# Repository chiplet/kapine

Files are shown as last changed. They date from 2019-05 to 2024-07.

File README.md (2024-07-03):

# KAPINE
Kircular Accelerator Prototype Innovative New Experience

# Setup

## KiCAD Library Setup
Run the following command to install the third party KiCAD libraries used in the project

`git submodule update --init --recursive`

This project uses components from [digikey-kicad-library](https://github.com/Digi-Key/digikey-kicad-library) which is configured as a git submodule of this project. Git doesn't clone submodules of a project by default when the project it is cloned so this has to be done manually.

# Hardware

## Pinout

**Application Signal Descriptions**
* m[0..15] -- Electromagnet control signals
* s[0..15] -- Photogate sensor input signals
* Debug 1 -- Debug led 1
* Debug 2 -- Debug led 2
* USART1 -- Command link UART

| Microcontroller Pin | Application Signal | Direction | Alternate Function |
|---|---|---|---|
| PB5 | m0 | Digital out | TBD |
| PD2 | m1 | Digital out | TBD |
| PC11 | m2 | Digital out | TBD |
| PA12 | m3 | Digital out | TBD |
| PA8 | m4 | Digital out | TBD |
| PC8 | m5 | Digital out | TBD |
| PC6 | m6 | Digital out | TBD |
| PB14 | m7 | Digital out | TBD |
| PB11 | m8 | Digital out | TBD |
| PB2 | m9 | Digital out | TBD |
| PC5 | m10 | Digital out | TBD |
| ~~PA3~~ PA4 | m11 | Digital out | TBD |
| PC3 | m12 | Digital out | TBD |
| PC1 | m13 | Digital out | TBD |
| PB9 | m14 | Digital out | TBD |
| PB7 | m15 | Digital out | TBD |
| PB4 | s0 | Digital in  | TBD |
| ~~PC12~~ PA3 | s1 | Digital in  | TBD |
| PC10 | s2 | Digital in  | TBD |
| PA11 | s3 | Digital in  | TBD |
| PC9 | s4 | Digital in  | TBD |
| PC7 | s5 | Digital in  | TBD |
| PB15 | s6 | Digital in  | TBD |
| PB13 | s7 | Digital in  | TBD |
| PB10 | s8 | Digital in  | TBD |
| PB1 | s9 | Digital in  | TBD |
| ~~PC4~~ PC14 | s10 | Digital in  | TBD |
| PA2 | s11 | Digital in  | TBD |
| ~~PC2~~ PA5 | s12 | Digital in  | TBD |
| PC0 | s13 | Digital in  | TBD |
| PB8 | s14 | Digital in  | TBD |
| PB6 | s15 | Digital in  | TBD |
| PA0 | Debug 1 | Digital out | TBD |
| PA1 | Debug 2 | Digital out | TBD |
| PA9 | USART1_TX | Digital out | AF7 |
| PA10 | USART1_RX | Digital in  | AF7 |
| PC13 | RGB LEDs | Digital out | TBD |

### Change Log
* 2021-08-07: STM32F3 maps GPIO to EXTI interrupts based on pin number. The following changes needed to be made to support interrupts on all sensor input pins:
  * m11 (PA3 -> PA4)
  * s2 (PC10 -> PA3)
  * s12 (PC2 -> PA5)
  * s10 (PC4 -> PC14)

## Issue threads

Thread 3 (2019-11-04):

Acrylic core with a detachable section for module interchange

chiplet, 2019-11-04:
* [x] Find where to buy appropriate acrylic tubing
* [ ] How to bend the tube to a perfect circle?
* [ ] Make jig for bending the tube

chiplet, 2024-07-03:
Acrylic was difficult to bend consistently so going for bare 3D printed accelerator tube.

Closed 2024-07-03.

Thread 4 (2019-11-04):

Self-contained accelerator modules with integrated sensors, communication bus, actuators, and debug interface

VerkkuUkkeli, 2019-11-04:
TODO: elaborate

VerkkuUkkeli, 2019-12-21:
Duplicate of #6

VerkkuUkkeli, 2019-12-21:
Reconsidering this, #6 is more about the electronics design for the segment control unit. This issue is about the status of the whole segment, including electrical and mechanical design.

VerkkuUkkeli, 2020-01-26:
SCUs will be no longer used so the issue is obsolete.

Closed 2020-01-26.

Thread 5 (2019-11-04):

Design motherboard v1

chiplet, 2019-11-04:
General:
* [x] choose microcontroller [STM32F303RE](https://www.digikey.fi/products/fi/integrated-circuits-ics/embedded-microcontrollers/685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)
* [x] board schematics
* [x] board layout

Power Supply:
* It's probably best to use a separate power supply for powering the electromagnet coils and the control circuitry to avoid EMC issues
* [x] regulate required voltages from an external wall wart
  * [x] 3.3V for the microcontroller digital logic
  * [x] 3.3V microcontroller analog reference

Interfaces:
* [x] JTAG
* [x] ST-LINK/V2-1 debugger
* [x] stack connector(s) to electromagnet driver board

TODO:
* [x] Logic level conversion from mcu to RGB

Ottis1, 2019-12-21:
This is not needed anymore since motherboard functionality is assigned to one of the segments?

VerkkuUkkeli, 2020-01-26:
MCU selection:
* All analog circuitry (photo gate sensors) shall convert their measures to digital format so the microcontroller does not have to deal with analog signals.

MCU requirements
* [ ] Enough GPIO pins (at least to support for adding IO expansion for all required signals)
  * segment indicator LEDs (16)
  * motherboard RGB (1)
  * driver board RGB (1) (can be chained with motherboard RGB)
  * electromagnet control signals (16)
  * debug UART (2)
* [ ] UART
* [ ] QFP package

VerkkuUkkeli, 2020-01-26:
## GPIO expansion considerations
Segment indicator LEDs can be driven with the control signals without much issue. A good solution would be to use a LED driver IC with 16 outputs and serial control interface, or maybe even a shift register.

IO expansion ICs allow for bidirectional I/O. This is not necessary for the segment indicators, but would be useful for reading sensors.

Shift registers:
[SN74HC595](https://www.digikey.fi/product-detail/fi/texas-instruments/SN74HC595PWR/296-23258-1-ND/1830780) is currently used for prototyping. These can be chained so 16 indicator LEDs can be controlled over a serial connection with 3 lines in total.

VerkkuUkkeli, 2020-08-16:
## MCU Implementation

TODO:
[ ] Copy reference design from STM32F3 hardware development [app note](https://www.st.com/resource/en/application_note/dm00070391-getting-started-with-stm32f3-series-hardware-development-stmicroelectronics.pdf)

chiplet, 2020-10-31:
First revision design is complete!

Closed 2020-10-31.

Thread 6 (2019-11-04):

Design Segment Control Unit (SCU) v1 electronics

VerkkuUkkeli, 2019-11-04:
General:
* [x] choose microcontroller
* [ ] sensor circuit
* [ ] electromagnet driver circuit
* [ ] board schematics
* [ ] board layout

Interfaces:
* [x] design debugger interface -- using SWD from STM32F0DISCOVERY board (ST-LINK/V2)
* [x] choose communication bus

VerkkuUkkeli, 2019-11-04:
MCU functions:
* photogate sensor(s)
  - read sensor value (analogue)
  - control IR diode
* drive high(ish) voltage electromagnet
  - control relay/FET
* indicator led(s) for magnet position
* debug
  - UART

MCU requirements
* [ ] ADC
* [ ] GPIO (at least 3)
* [ ] UART
* [ ] Small footprint
* [ ] QFP package
* [ ] Low cost

VerkkuUkkeli, 2019-12-18:
[STM32F072C8T6TR](https://www.digikey.fi/product-detail/en/stmicroelectronics/STM32F072C8T6TR/497-17359-1-ND/8024128) looks like a suitable MCU.

[datasheet](https://www.st.com/content/ccc/resource/technical/document/datasheet/cd/46/43/83/22/d3/40/c8/DM00090510.pdf/files/DM00090510.pdf/jcr:content/translations/en.DM000905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)

VerkkuUkkeli, 2019-12-18:
Also remember to by a [STM32F0 discovery](https://www.digikey.fi/product-detail/en/stmicroelectronics/STM32F0DISCOVERY/497-12876-ND/3045359) board for flashing.

VerkkuUkkeli, 2019-12-18:
TODO:
* [ ] Choose regulator(s) for MCU
* [ ] Choose flashing interface connector
* [ ] Choose FETs / relays used
* [ ] Choose CAN transceiver

VerkkuUkkeli, 2019-12-21:
HSE crystal selection:

[ECS-80-18-30B-JEM-TR](https://www.digikey.fi/product-detail/fi/ecs-inc/ECS-80-18-30B-JEM-TR/XC2105CT-ND/5875589) seems suitable.

gain margin = 18.7 (> 5 so all good)

computed with values:
* ESR = 100 ohm
* C_L = 18pF
* C_0 = 5pF
* F = 8 MHz
* g_m = 10 mA/V

See [AN2867](https://www.st.com/content/ccc/resource/technical/document/application_note/c6/eb/5e/11/e3/69/43/eb/CD00221665.pdf/files/CD00221665.pdf/jcr:content/translations/en.C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) section 3.4 for formulae

VerkkuUkkeli, 2019-12-22:
There probably isn't going to be enough space for a relay... :(

Relays would be nice because they make nice clicking sounds, but they are slow and big compared to load switches. Load switches also seem to be preferable over using plain FETs as they have adequate current and voltage range (4A at 12V) with much smaller footprint and additional protection circuitry.

[BTS50451EJAXUMA1](https://www.digikey.fi/product-detail/fi/infineon-technologies/BTS50451EJAXUMA1/BTS50451EJAXUMA1CT-ND/5413734) seems promising for the electromagnet driver. The max load inductance must still be verified to see if this IC can be used for driving the electromagnet.

VerkkuUkkeli, 2020-01-26:
SCUs will be no longer used so the issue is obsolete.

Closed 2020-01-26.

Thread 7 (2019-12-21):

Configure SCU CAN peripheral

VerkkuUkkeli, 2019-12-21:
Configure STM32F072 bxCAN peripheral for use.

TODO:
* [ ] Enable peripheral clock (CANEN bit in RCC_APB1ENR register)
* [ ] Configure APB clock (PCLK)
* [ ] Bit timing -- prescaler for bxCAN
* [ ] Bit timing -- nominal bit timing and sample point ([see spec](http://esd.cs.ucr.edu/webres/can20.pdf))

VerkkuUkkeli, 2019-12-21:
The bxCAN peripheral uses APB bus clock (PCLK).

VerkkuUkkeli, 2020-01-26:
SCUs will be no longer used so the issue is obsolete.

Closed 2020-01-26.

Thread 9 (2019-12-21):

Segment CAD design

chiplet, 2019-12-21:
CAD design for accelerator segments

TODO and things to consider:
* [x] accommodate segment PCBs
* [x] accommodate photo gate sensor
* [x] accommodate electromagnet
* [ ] ~~places for electrical connectors for inter-module connections (chain units together)~~
* [ ] cable management
* [ ] EMC issues and wiring placement (try to minimise interference by smart cable routing)
* [x] how to manufacture, design with manufacturing in mind (3D printing?)

TODO: add more considerations as they come up

VerkkuUkkeli, 2020-02-20:
## Sensor placement considerations:
* [ ] Should the pipe have a hole for mounting the sensors
  * [ ] Test if the sensor works through the pipe without mounting holes

VerkkuUkkeli, 2020-03-21:
Relays / FETs are placed on top of the motherboard so there will be no need to try to accommodate them in the segments.

Ottis1, 2021-01-19:
It seems to me that only the cable management and wiring placement considerations are left in this issue. Controlling the segments happens on the motherboard so there will be no segment PCBs. Also, in my understanding the units will not be chained together in any way.
3D printing was chosen as the manufacturing method.

chiplet, 2024-07-06:
Segments have been designed and printed already

Closed 2024-07-06.

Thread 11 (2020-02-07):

Motherboard clock configuration

chiplet, 2020-02-07:
Configure the MCU to use the HSE as the clock source.

The following part of the [hardware design guide](https://www.st.com/content/ccc/resource/technical/document/application_note/31/14/f4/9d/d3/8f/48/2b/DM00070391.pdf/files/DM00070391.pdf/jcr:content/translations/en.D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) seems useful for software configuration:
"The HSERDY flag in the Clock control register (RCC_CR) indicates if the HSE oscillator is
stable or not. At startup, the clock is not released until this bit is set by hardware. An
interrupt can be generated if enabled in the Clock interrupt register (RCC_CIR).
The HSE Crystal can be switched on and off using the HSEON bit in the Clock control
register (RCC_CR)."

chiplet, 2024-07-06:
Done. The stm32f3xx-hal crate offers a convenient interface for configuring core and peripheral clocks:
https://docs.rs/stm32f3xx-hal/0.10.0/stm32f3xx_hal/rcc/index.html

Closed 2024-07-06.

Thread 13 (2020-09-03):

Design relelauta v.2.0

chiplet, 2020-09-03:
# Abbreviations
* EM - electromagnet

# TODO:
* [x] Measure EM inductance
* [x] Choose EM driver
  * Relay?
  * Load switch?
  * MOSFET?
* [ ] Indicator LEDs for EM drivers
  * [ ] Amplifiers for indicator led signal so that EM control signals are not loaded by the LEDs

## Electromagnet Specifications
* Resistance ~2 Ohm
* Inductance ~ 430 µH
=> Assuming 10A current, energy stored in inductor is E = 22mJ

## Electromagnet driver selection considerations
* High enough load current (around 10A, TBD)
* High enough power package to withstand generated heat
* Be able to withstand inductive "kicks" when switching off the electromagnet
  * Are external flywheel diodes required?
* Nice enough package for easy soldering

chiplet, 2021-01-18:
STM32 GPIO pins are a bit problematic, at least on the Blue Pill dev board. According to the reference manual, the GPIO pins should reset to floating input configuration. The configuration register contents match this configuration when inspecting memory. However, for whatever reason, when measured, the pin is pulled up to 3.3V. The boards were ordered from ebay so the issue might be that the MCU on the devboard is actually a clone which doesn't implement the floating state correctly.

Whatever the reason, this is problematic since when the pin is pulled to 3.3V an electromagnet controlled by the pin would turn on. This is not an issue after the pin has been configured as an output. However, when debugging with a breakpoint set to main, this would turn on **all** electromagnets by default at the same time and the electronics are not designed to handle that.

As a workaround I'm connecting an external 1k pull-down resistor which seems to pull the pin to around 0.7V when left "floating".

Closed 2021-05-16.

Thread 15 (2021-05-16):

Motherboard firmware

Ottis1, 2021-05-16:
Develop the firmware for the motherboard which controls the electromagnets, reads the sensors and communicates with the PC command interface via a serial connection.

TODO:

- [ ] serial communication
- [ ]

chiplet, 2024-07-06:
**TODO:**
- [ ] Serial communication
  - [ ] USART1 driver
  - [ ] Packet-based request-acknowledge command link
- [x] RGB animation (make it look like cool alien brains!)
- [ ] Sensor input interrupts
- [ ] Acceleration control sequencing

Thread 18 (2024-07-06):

Motherboard v1.3

chiplet, 2024-07-06:
Create a new motherboard hardware revision fixing the pin assignment issues in motherboard v1.2. At least RGB data signal has been moved to PA7 corresponding to SPI1_MOSI with AF5.

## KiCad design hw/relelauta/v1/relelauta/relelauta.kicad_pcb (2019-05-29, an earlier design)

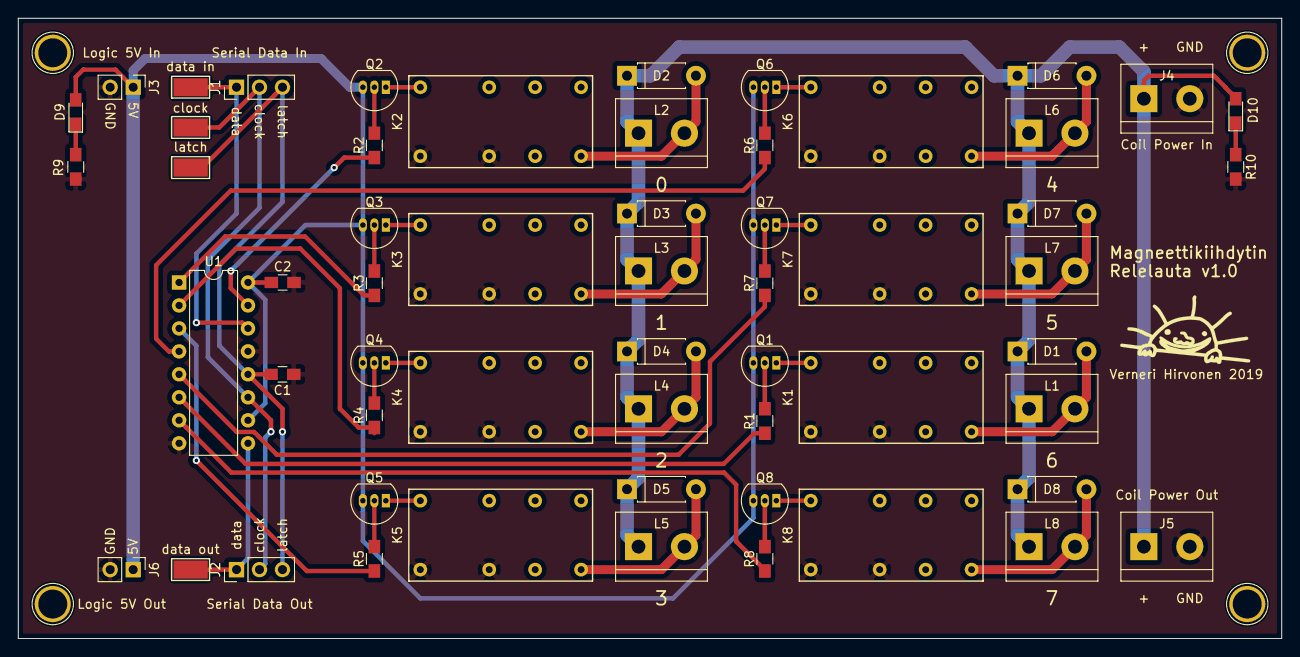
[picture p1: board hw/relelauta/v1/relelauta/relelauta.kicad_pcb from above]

Board: 2 copper layers, 139.7 x 68.6 mm, 57 parts (0 on the bottom side), 41 nets.

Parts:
C1, C2: 100n; C_0805_HandSoldering
D1, D2, D3, D4, D5, D6, D7, D8: 1N4001; D_DO-41_SOD81_P7.62mm_Horizontal
D9: ARDUINO; LED_0805_HandSoldering
D10: COIL; LED_0805_HandSoldering
J1: serial_in; Pin_Header_Straight_1x03_Pitch2.54mm
J2: serial_out; Pin_Header_Straight_1x03_Pitch2.54mm
J3: arduino_5V; Pin_Header_Straight_1x02_Pitch2.54mm
J4: coil_power_in; TerminalBlock_bornier-2_P5.08mm
J5: coil_power_out; TerminalBlock_bornier-2_P5.08mm
J6: 5V_out; Pin_Header_Straight_1x02_Pitch2.54mm
K1: relay 7; RY5W-K
K2: relay 1; RY5W-K
K3: relay 2; RY5W-K
K4: relay 3; RY5W-K
K5: relay 4; RY5W-K
K6: relay 5; RY5W-K
K7: relay 6; RY5W-K
K8: relay 8; RY5W-K
L1: coil7; TerminalBlock_bornier-2_P5.08mm
L2: coil1; TerminalBlock_bornier-2_P5.08mm
L3: coil2; TerminalBlock_bornier-2_P5.08mm
L4: coil3; TerminalBlock_bornier-2_P5.08mm
L5: coil4; TerminalBlock_bornier-2_P5.08mm
L6: coil5; TerminalBlock_bornier-2_P5.08mm
L7: coil6; TerminalBlock_bornier-2_P5.08mm
L8: coil8; TerminalBlock_bornier-2_P5.08mm
Q1, Q2, Q3, Q4, Q5, Q6, Q7, Q8: 2N3904; TO-92_Inline_Narrow_Oval
R1, R2, R3, R4, R5, R6, R7, R8: 1k; R_0805_HandSoldering
R9, R10: 10k; R_0805_HandSoldering
U1: 74HC595; DIP-16_W7.62mm
clock: clock; Test_Point_Keystone_5019_Minature
data in: data_in; Test_Point_Keystone_5019_Minature
data out: data_out; Test_Point_Keystone_5019_Minature
latch: latch; Test_Point_Keystone_5019_Minature

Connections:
+5V: C2.1, D9.2, J3.1, J6.1, Q1.3, Q2.3, Q3.3, Q4.3, Q5.3, Q6.3, Q7.3, Q8.3, U1.10, U1.16
GND: C1.1, C2.2, J3.2, J4.2, J5.2, J6.2, K1.21, K1.A2, K2.21, K2.A2, K3.21, K3.A2, K4.21, K4.A2, K5.21, K5.A2, K6.21, K6.A2, K7.21, K7.A2, K8.21, K8.A2, R9.2, R10.2, U1.8, U1.13
unnamed: D1.2, K1.24, L1.2
unnamed: D2.2, K2.24, L2.2
unnamed: D3.2, K3.24, L3.2
unnamed: D4.2, K4.24, L4.2
unnamed: D5.2, K5.24, L5.2
unnamed: D6.2, K6.24, L6.2
unnamed: D7.2, K7.24, L7.2
unnamed: D8.2, K8.24, L8.2
unnamed: D9.1, R9.1
unnamed: D10.1, R10.1
unnamed: K1.A1, Q1.1
unnamed: K2.A1, Q2.1
unnamed: K3.A1, Q3.1
unnamed: K4.A1, Q4.1
unnamed: K5.A1, Q5.1
unnamed: K6.A1, Q6.1
unnamed: K7.A1, Q7.1
unnamed: K8.A1, Q8.1
unnamed: Q1.2, R1.2
unnamed: Q2.2, R2.2
unnamed: Q3.2, R3.2
unnamed: Q4.2, R4.2
unnamed: Q5.2, R5.2
unnamed: Q6.2, R6.2
unnamed: Q7.2, R7.2
unnamed: Q8.2, R8.2
V_coil: D1.1, D2.1, D3.1, D4.1, D5.1, D6.1, D7.1, D8.1, D10.2, J4.1, J5.1, L1.1, L2.1, L3.1, L4.1, L5.1, L6.1, L7.1, L8.1
clock: J1.2, J2.2, U1.11, clock.1
data_in: J1.1, U1.14, data in.1
data_out: J2.1, U1.9, data out.1
latch: C1.2, J1.3, J2.3, U1.12, latch.1
signal1: R2.1, U1.15
signal2: R3.1, U1.1
signal3: R4.1, U1.2
signal4: R5.1, U1.3
signal5: R6.1, U1.4
signal6: R7.1, U1.5
signal7: R1.1, U1.6
signal8: R8.1, U1.7

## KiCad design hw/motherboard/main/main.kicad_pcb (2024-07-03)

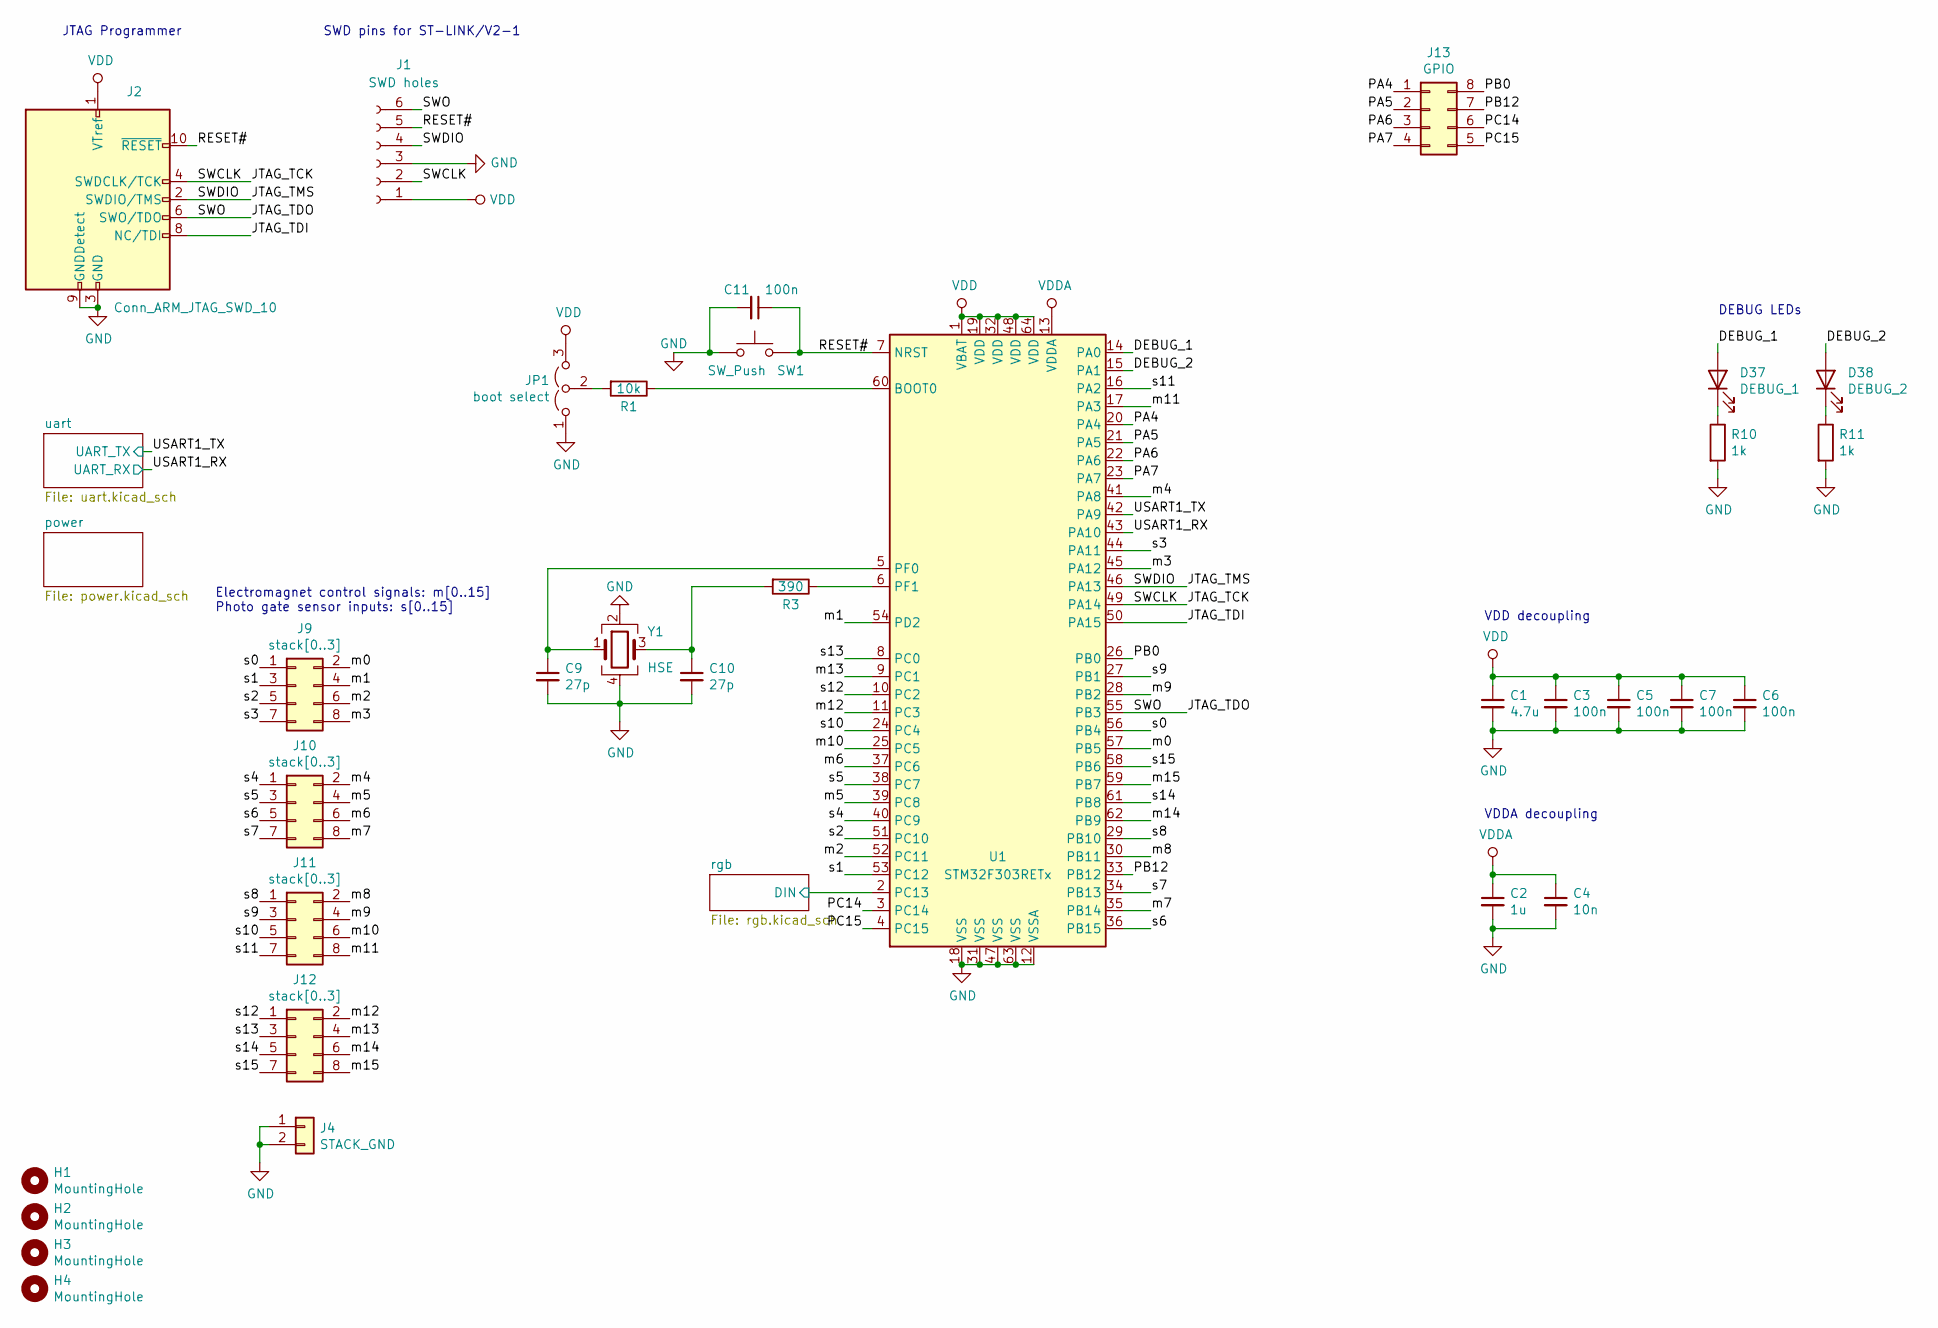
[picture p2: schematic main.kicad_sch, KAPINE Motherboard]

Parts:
C1: 4.7u; C_0805_2012Metric
C2: 1u; C_0603_1608Metric
C3, C5, C6, C7, C11: 100n; C_0603_1608Metric
C4: 10n; C_0603_1608Metric
C9, C10: 27p; C_0603_1608Metric
D37: DEBUG_1; LED_0805_2012Metric
D38: DEBUG_2; LED_0805_2012Metric
H1, H2, H3, H4: MountingHole; MountingHole_4.3mm_M4
J1: SWD holes; PinHeader_1x06_P2.54mm_Vertical
J2: Conn_ARM_JTAG_SWD_10; PinHeader_2x5_P1.27mm_Drill.7mm
J4: STACK_GND; PinSocket_1x02_P2.54mm_Vertical
J9, J10, J11, J12: stack[0..3]; PinSocket_2x04_P2.54mm_Vertical
J13: GPIO; PinHeader_2x04_P2.54mm_Vertical
JP1: boot select; PinHeader_1x03_P2.54mm_Vertical
R1: 10k; R_0603_1608Metric
R3: 390; R_0603_1608Metric
R10, R11: 1k; R_0805_2012Metric
SW1: SW_Push; SW_SPST_TL3342
U1: STM32F303RETx; LQFP-64_10x10mm_P0.5mm
Y1: HSE; Crystal_SMD_Abracon_ABM3C-4Pin_5.0x3.2mm

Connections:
/DEBUG_1: D37.2 (A), U1.14 (PA0)
/DEBUG_2: D38.2 (A), U1.15 (PA1)
/JTAG_TCK: J1.2, J2.4 (SWDCLK/TCK), U1.49 (PA14)
/JTAG_TDI: J2.8 (NC/TDI), U1.50 (PA15)
/JTAG_TDO: J1.6, J2.6 (SWO/TDO), U1.55 (PB3)
/JTAG_TMS: J1.4, J2.2 (SWDIO/TMS), U1.46 (PA13)
/PA4: J13.1, U1.20 (PA4)
/PA5: J13.2, U1.21 (PA5)
/PA6: J13.3, U1.22 (PA6)
/PA7: J13.4, U1.23 (PA7)
/PB0: J13.8, U1.26 (PB0)
/PB12: J13.7, U1.33 (PB12)
/PC14: J13.6, U1.3 (PC14)
/PC15: J13.5, U1.4 (PC15)
/RESET#: C11.1, J1.5, J2.10 (~RESET), SW1.2, U1.7 (NRST)
/USART1_RX: U1.43 (PA10); also elsewhere on the board
/USART1_TX: U1.42 (PA9); also elsewhere on the board
/m0: J9.2, U1.57 (PB5)
/m1: J9.4, U1.54 (PD2)
/m2: J9.6, U1.52 (PC11)
/m3: J9.8, U1.45 (PA12)
/m4: J10.2, U1.41 (PA8)
/m5: J10.4, U1.39 (PC8)
/m6: J10.6, U1.37 (PC6)
/m7: J10.8, U1.35 (PB14)
/m8: J11.2, U1.30 (PB11)
/m9: J11.4, U1.28 (PB2)
/m10: J11.6, U1.25 (PC5)
/m11: J11.8, U1.17 (PA3)
/m12: J12.2, U1.11 (PC3)
/m13: J12.4, U1.9 (PC1)
/m14: J12.6, U1.62 (PB9)
/m15: J12.8, U1.59 (PB7)
/rgb/DIN: U1.2 (PC13); also elsewhere on the board
/s0: J9.1, U1.56 (PB4)
/s1: J9.3, U1.53 (PC12)
/s2: J9.5, U1.51 (PC10)
/s3: J9.7, U1.44 (PA11)
/s4: J10.1, U1.40 (PC9)
/s5: J10.3, U1.38 (PC7)
/s6: J10.5, U1.36 (PB15)
/s7: J10.7, U1.34 (PB13)
/s8: J11.1, U1.29 (PB10)
/s9: J11.3, U1.27 (PB1)
/s10: J11.5, U1.24 (PC4)
/s11: J11.7, U1.16 (PA2)
/s12: J12.1, U1.10 (PC2)
/s13: J12.3, U1.8 (PC0)
/s14: J12.5, U1.61 (PB8)
/s15: J12.7, U1.58 (PB6)
GND: C1.2, C2.2, C3.2, C4.2, C5.2, C6.2, C7.2, C9.2, C10.2, C11.2, J1.3, J2.3 (GND), J2.5 (GND), J2.9 (GNDDetect), J4.1, J4.2, JP1.1 (A), R10.2, R11.2, SW1.1, U1.12 (VSSA), U1.18 (VSS), U1.31 (VSS), U1.47 (VSS), U1.63 (VSS), Y1.2, Y1.4; also elsewhere on the board
unnamed: C9.1, U1.5 (PF0), Y1.1
unnamed: C10.1, R3.2, Y1.3
unnamed: D37.1 (K), R10.1
unnamed: D38.1 (K), R11.1
unnamed: JP1.2 (C), R1.2
unnamed: R1.1, U1.60 (BOOT0)
unnamed: R3.1, U1.6 (PF1)
VDD: C1.1, C3.1, C5.1, C6.1, C7.1, J1.1, J2.1 (VTref), JP1.3 (B), U1.1 (VBAT), U1.19 (VDD), U1.32 (VDD), U1.48 (VDD), U1.64 (VDD); also elsewhere on the board
VDDA: C2.1, C4.1, U1.13 (VDDA); also elsewhere on the board

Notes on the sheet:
VDD decoupling
Electromagnet control signals: m[0..15] Photo gate sensor inputs: s[0..15]
SWD pins for ST-LINK/V2-1
JTAG Programmer
DEBUG LEDs
VDDA decoupling

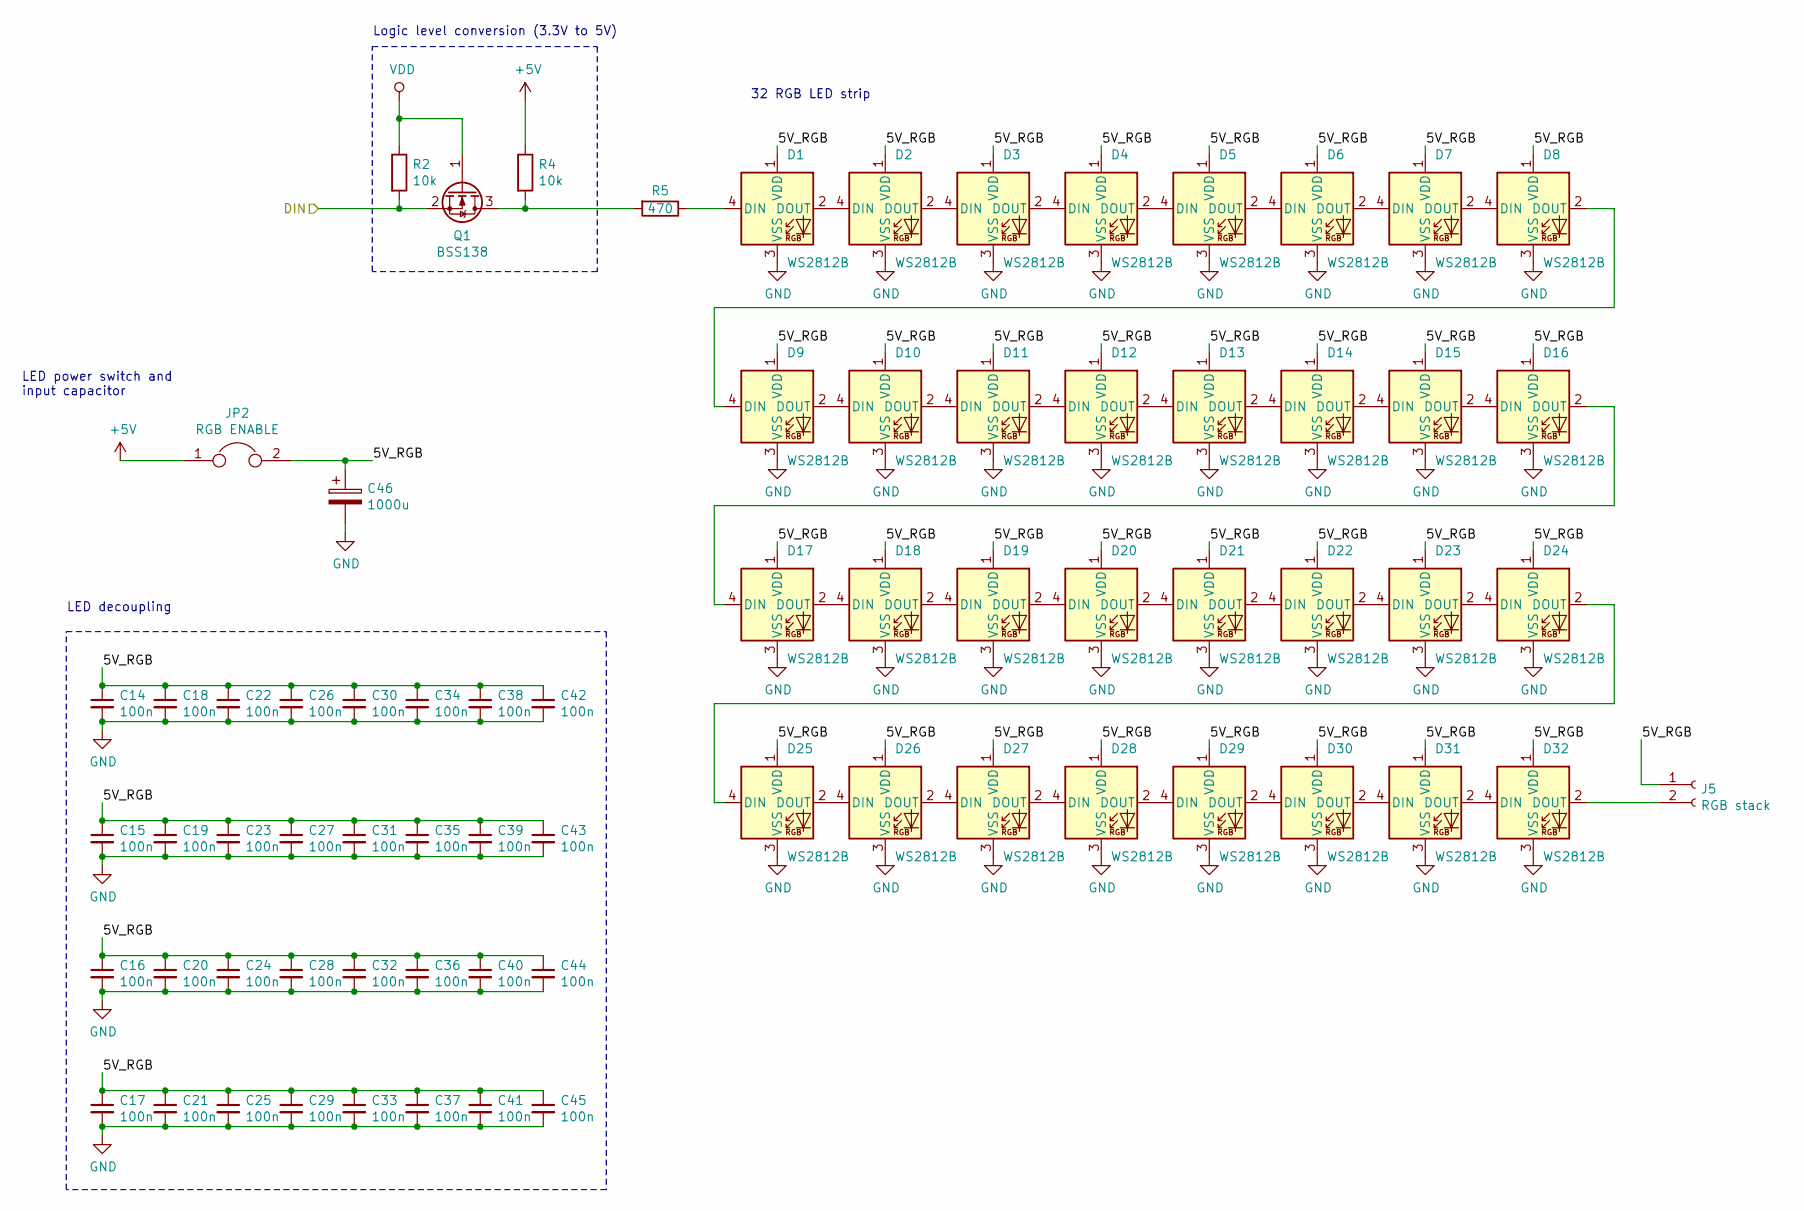
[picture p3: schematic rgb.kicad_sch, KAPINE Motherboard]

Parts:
C14, C15, C16, C17, C18, C19, C20, C21, C22, C23, C24, C25, C26, C27, C28, C29, C30, C31, C32, C33, C34, C35, C36, C37, C38, C39, C40, C41, C42, C43, C44, C45: 100n; C_0603_1608Metric
C46: 1000u; CP_Elec_10x10
D1, D2, D3, D4, D5, D6, D7, D8, D9, D10, D11, D12, D13, D14, D15, D16, D17, D18, D19, D20, D21, D22, D23, D24, D25, D26, D27, D28, D29, D30, D31, D32: WS2812B; LED_WS2812B_PLCC4_5.0x5.0mm_P3.2mm
J5: RGB stack; PinSocket_1x02_P2.54mm_Vertical
JP2: RGB ENABLE; PinHeader_1x02_P2.54mm_Vertical
Q1: BSS138; SOT-23
R2, R4: 10k; R_0603_1608Metric
R5: 470; R_0603_1608Metric

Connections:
+5V: JP2.1, R4.1; also elsewhere on the board
/rgb/5V_RGB: C14.1, C15.1, C16.1, C17.1, C18.1, C19.1, C20.1, C21.1, C22.1, C23.1, C24.1, C25.1, C26.1, C27.1, C28.1, C29.1, C30.1, C31.1, C32.1, C33.1, C34.1, C35.1, C36.1, C37.1, C38.1, C39.1, C40.1, C41.1, C42.1, C43.1, C44.1, C45.1, C46.1, D1.1 (VDD), D2.1 (VDD), D3.1 (VDD), D4.1 (VDD), D5.1 (VDD), D6.1 (VDD), D7.1 (VDD), D8.1 (VDD), D9.1 (VDD), D10.1 (VDD), D11.1 (VDD), D12.1 (VDD), D13.1 (VDD), D14.1 (VDD), D15.1 (VDD), D16.1 (VDD), D17.1 (VDD), D18.1 (VDD), D19.1 (VDD), D20.1 (VDD), D21.1 (VDD), D22.1 (VDD), D23.1 (VDD), D24.1 (VDD), D25.1 (VDD), D26.1 (VDD), D27.1 (VDD), D28.1 (VDD), D29.1 (VDD), D30.1 (VDD), D31.1 (VDD), D32.1 (VDD), J5.1, JP2.2
/rgb/DIN: Q1.2 (S), R2.2; also elsewhere on the board
GND: C14.2, C15.2, C16.2, C17.2, C18.2, C19.2, C20.2, C21.2, C22.2, C23.2, C24.2, C25.2, C26.2, C27.2, C28.2, C29.2, C30.2, C31.2, C32.2, C33.2, C34.2, C35.2, C36.2, C37.2, C38.2, C39.2, C40.2, C41.2, C42.2, C43.2, C44.2, C45.2, C46.2, D1.3 (VSS), D2.3 (VSS), D3.3 (VSS), D4.3 (VSS), D5.3 (VSS), D6.3 (VSS), D7.3 (VSS), D8.3 (VSS), D9.3 (VSS), D10.3 (VSS), D11.3 (VSS), D12.3 (VSS), D13.3 (VSS), D14.3 (VSS), D15.3 (VSS), D16.3 (VSS), D17.3 (VSS), D18.3 (VSS), D19.3 (VSS), D20.3 (VSS), D21.3 (VSS), D22.3 (VSS), D23.3 (VSS), D24.3 (VSS), D25.3 (VSS), D26.3 (VSS), D27.3 (VSS), D28.3 (VSS), D29.3 (VSS), D30.3 (VSS), D31.3 (VSS), D32.3 (VSS); also elsewhere on the board
unnamed: D1.2 (DOUT), D2.4 (DIN)
unnamed: D1.4 (DIN), R5.1
unnamed: D2.2 (DOUT), D3.4 (DIN)
unnamed: D3.2 (DOUT), D4.4 (DIN)
unnamed: D4.2 (DOUT), D5.4 (DIN)
unnamed: D5.2 (DOUT), D6.4 (DIN)
unnamed: D6.2 (DOUT), D7.4 (DIN)
unnamed: D7.2 (DOUT), D8.4 (DIN)
unnamed: D8.2 (DOUT), D9.4 (DIN)
unnamed: D10.2 (DOUT), D11.4 (DIN)
unnamed: D9.2 (DOUT), D10.4 (DIN)
unnamed: D11.2 (DOUT), D12.4 (DIN)
unnamed: D12.2 (DOUT), D13.4 (DIN)
unnamed: D13.2 (DOUT), D14.4 (DIN)
unnamed: D14.2 (DOUT), D15.4 (DIN)
unnamed: D15.2 (DOUT), D16.4 (DIN)
unnamed: D16.2 (DOUT), D17.4 (DIN)
unnamed: D17.2 (DOUT), D18.4 (DIN)
unnamed: D18.2 (DOUT), D19.4 (DIN)
unnamed: D19.2 (DOUT), D20.4 (DIN)
unnamed: D20.2 (DOUT), D21.4 (DIN)
unnamed: D21.2 (DOUT), D22.4 (DIN)
unnamed: D22.2 (DOUT), D23.4 (DIN)
unnamed: D23.2 (DOUT), D24.4 (DIN)
unnamed: D24.2 (DOUT), D25.4 (DIN)
unnamed: D25.2 (DOUT), D26.4 (DIN)
unnamed: D26.2 (DOUT), D27.4 (DIN)
unnamed: D27.2 (DOUT), D28.4 (DIN)
unnamed: D28.2 (DOUT), D29.4 (DIN)
unnamed: D29.2 (DOUT), D30.4 (DIN)
unnamed: D30.2 (DOUT), D31.4 (DIN)
unnamed: D31.2 (DOUT), D32.4 (DIN)
unnamed: D32.2 (DOUT), J5.2
unnamed: Q1.3 (D), R4.2, R5.2
VDD: Q1.1 (G), R2.1; also elsewhere on the board

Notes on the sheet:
32 RGB LED strip
LED decoupling
LED power switch and input capacitor
Logic level conversion (3.3V to 5V)

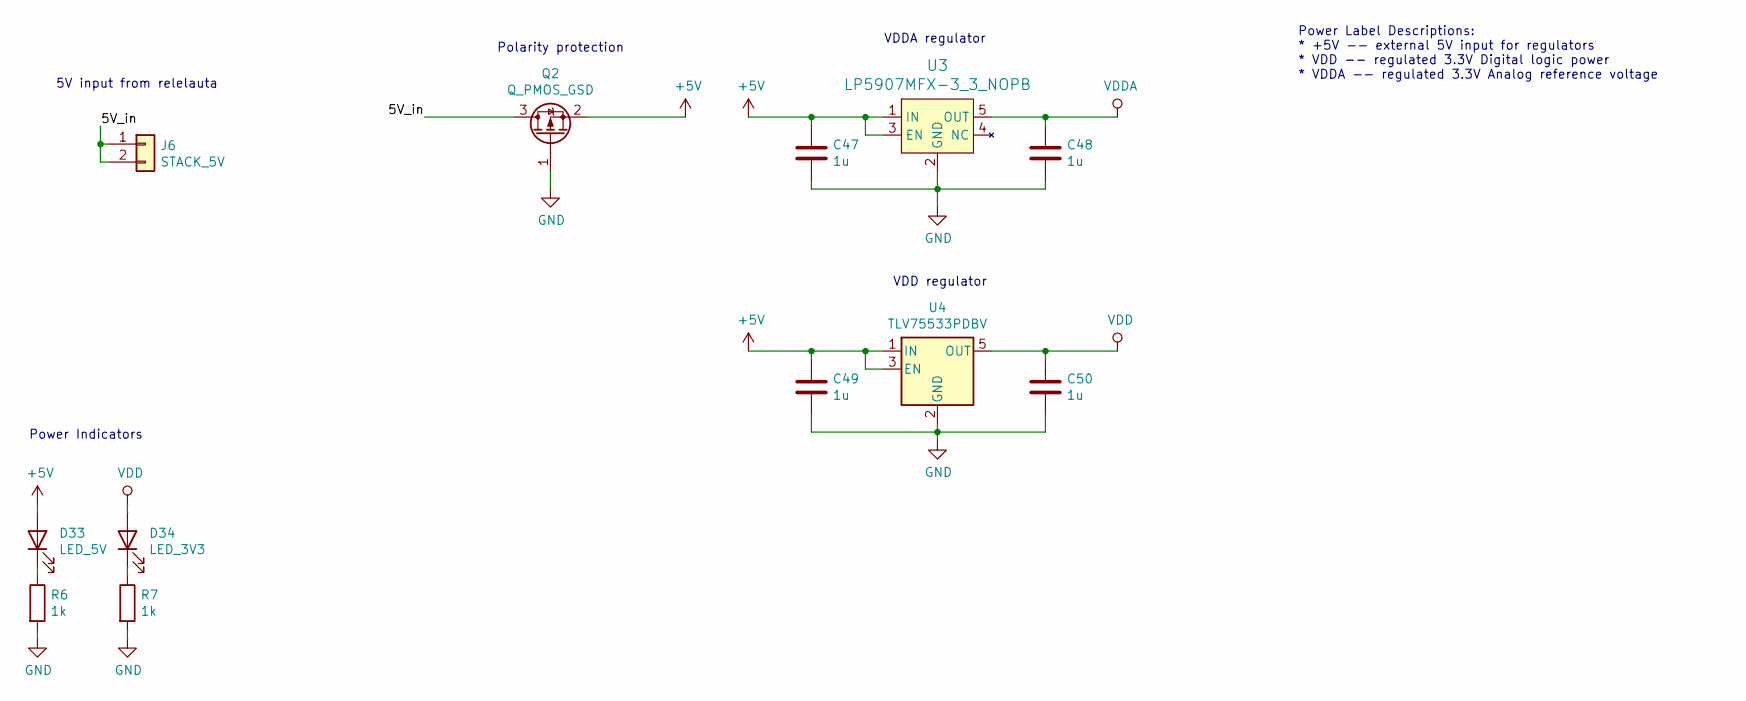
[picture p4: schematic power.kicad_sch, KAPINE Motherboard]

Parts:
C47, C48, C49, C50: 1u; C_0603_1608Metric
D33: LED_5V; LED_0805_2012Metric
D34: LED_3V3; LED_0805_2012Metric
J6: STACK_5V; PinSocket_1x02_P2.54mm_Vertical
Q2: Q_PMOS_GSD; SOT-23
R6, R7: 1k; R_0805_2012Metric
U3: LP5907MFX-3_3_NOPB; SOT-753; MPN LP5907MFX-3.3/NOPB; Digi-Key_PN 296-38557-1-ND
U4: TLV75533PDBV; SOT-23-5

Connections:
+5V: C47.1, C49.1, D33.2 (A), Q2.2 (S), U3.1 (IN), U3.3 (EN), U4.1 (IN), U4.3 (EN); also elsewhere on the board
/power/5V_in: J6.1, J6.2, Q2.3 (D)
GND: C47.2, C48.2, C49.2, C50.2, Q2.1 (G), R6.2, R7.2, U3.2 (GND), U4.2 (GND); also elsewhere on the board
unnamed: D33.1 (K), R6.1
unnamed: D34.1 (K), R7.1
VDD: C50.1, D34.2 (A), U4.5 (OUT); also elsewhere on the board
VDDA: C48.1, U3.5 (OUT); also elsewhere on the board

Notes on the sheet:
Power Label Descriptions: * +5V -- external 5V input for regulators * VDD -- regulated 3.3V Digital logic power * VDDA -- regulated 3.3V Analog reference voltage
5V input from relelauta
Polarity protection
VDDA regulator
Power Indicators
VDD regulator

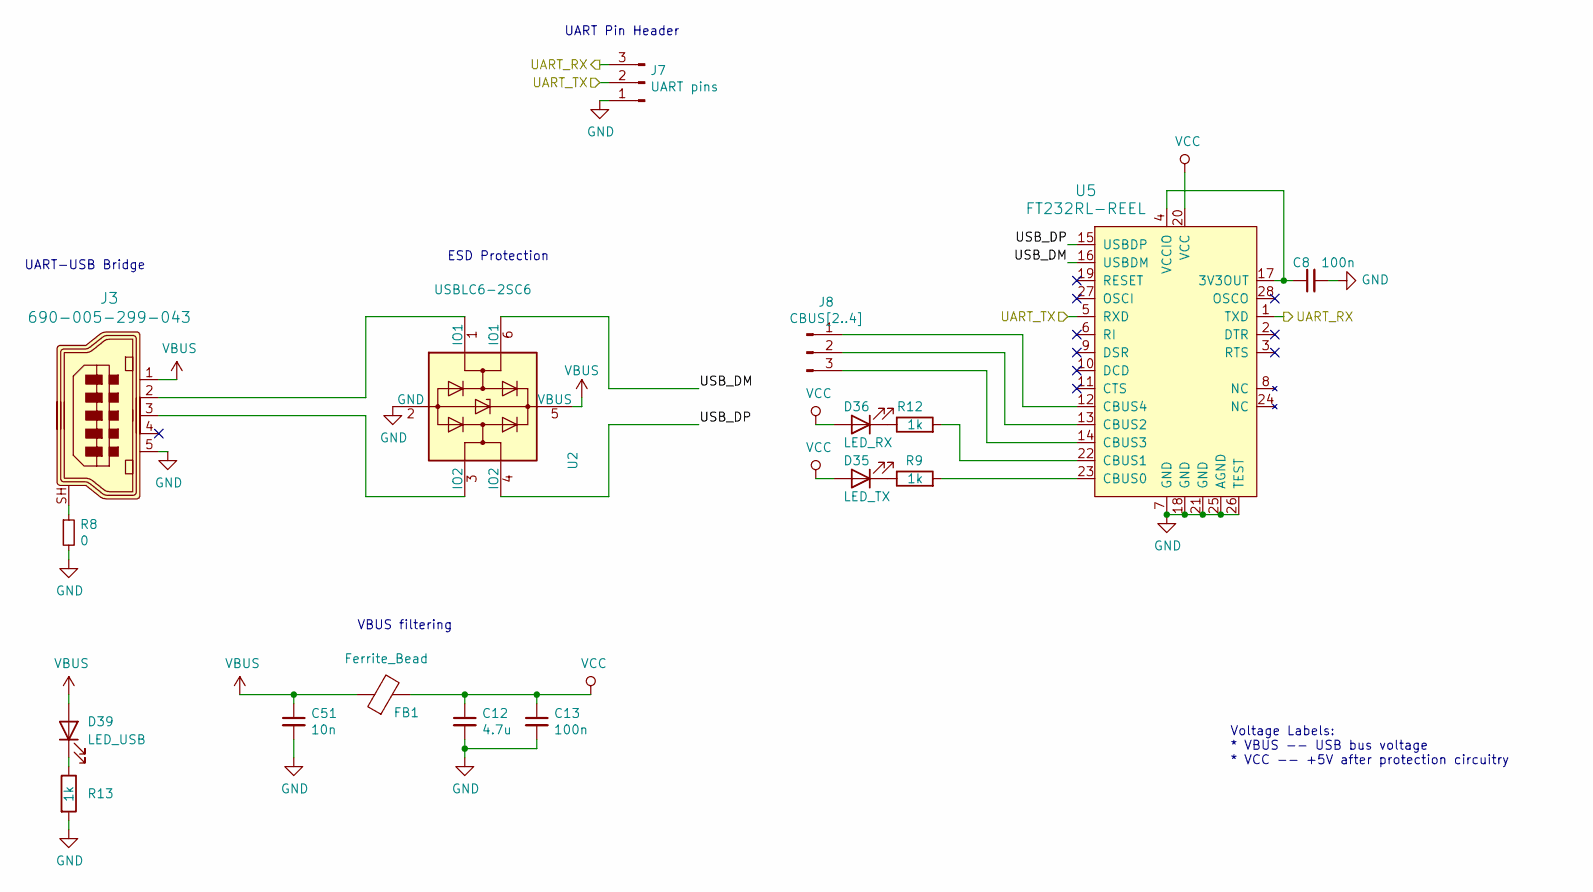
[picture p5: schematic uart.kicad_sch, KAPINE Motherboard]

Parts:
C8, C13: 100n; C_0603_1608Metric
C12: 4.7u; C_0805_2012Metric
C51: 10n; C_0603_1608Metric
D35: LED_TX; LED_0805_2012Metric
D36: LED_RX; LED_0805_2012Metric
D39: LED_USB; LED_0805_2012Metric
FB1: Ferrite_Bead; L_0603_1608Metric
J3: 690-005-299-043; USB_Mini_B_Female_690-005-299-043; MPN 690-005-299-043; Digi-Key_PN 151-1206-1-ND
J7: UART pins; PinHeader_1x03_P2.54mm_Vertical
J8: CBUS[2..4]; PinHeader_1x03_P1.27mm_Vertical
R8: 0; R_0603_1608Metric
R9, R12, R13: 1k; R_0805_2012Metric
U2: USBLC6-2SC6; SOT-23-6
U5: FT232RL-REEL; SSOP-28_W5.30mm; MPN FT232RL-REEL; Digi-Key_PN 768-1007-1-ND

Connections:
/USART1_RX: J7.3, U5.1 (TXD); also elsewhere on the board
/USART1_TX: J7.2, U5.5 (RXD); also elsewhere on the board
/uart/USB_DM: U2.6 (IO1), U5.16 (USBDM)
/uart/USB_DP: U2.4 (IO2), U5.15 (USBDP)
GND: C8.2, C12.2, C13.2, C51.2, J3.5, J7.1, R8.2, R13.2, U2.2 (GND), U5.7 (GND), U5.18 (GND), U5.21 (GND), U5.25 (AGND), U5.26 (TEST); also elsewhere on the board
unnamed: C8.1, U5.4 (VCCIO), U5.17 (3V3OUT)
unnamed: D35.1 (K), R9.1
unnamed: D36.1 (K), R12.1
unnamed: D39.1 (K), R13.1
unnamed: J3.2, U2.1 (IO1)
unnamed: J3.3, U2.3 (IO2)
unnamed: J3.SH, R8.1
unnamed: J8.1, U5.12 (CBUS4)
unnamed: J8.2, U5.13 (CBUS2)
unnamed: J8.3, U5.14 (CBUS3)
unnamed: R9.2, U5.23 (CBUS0)
unnamed: R12.2, U5.22 (CBUS1)
VBUS: C51.1, D39.2 (A), FB1.1, J3.1, U2.5 (VBUS)
VCC: C12.1, C13.1, D35.2 (A), D36.2 (A), FB1.2, U5.20 (VCC)

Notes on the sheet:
UART Pin Header
UART-USB Bridge
VBUS filtering
Voltage Labels: * VBUS -- USB bus voltage * VCC -- +5V after protection circuitry
ESD Protection

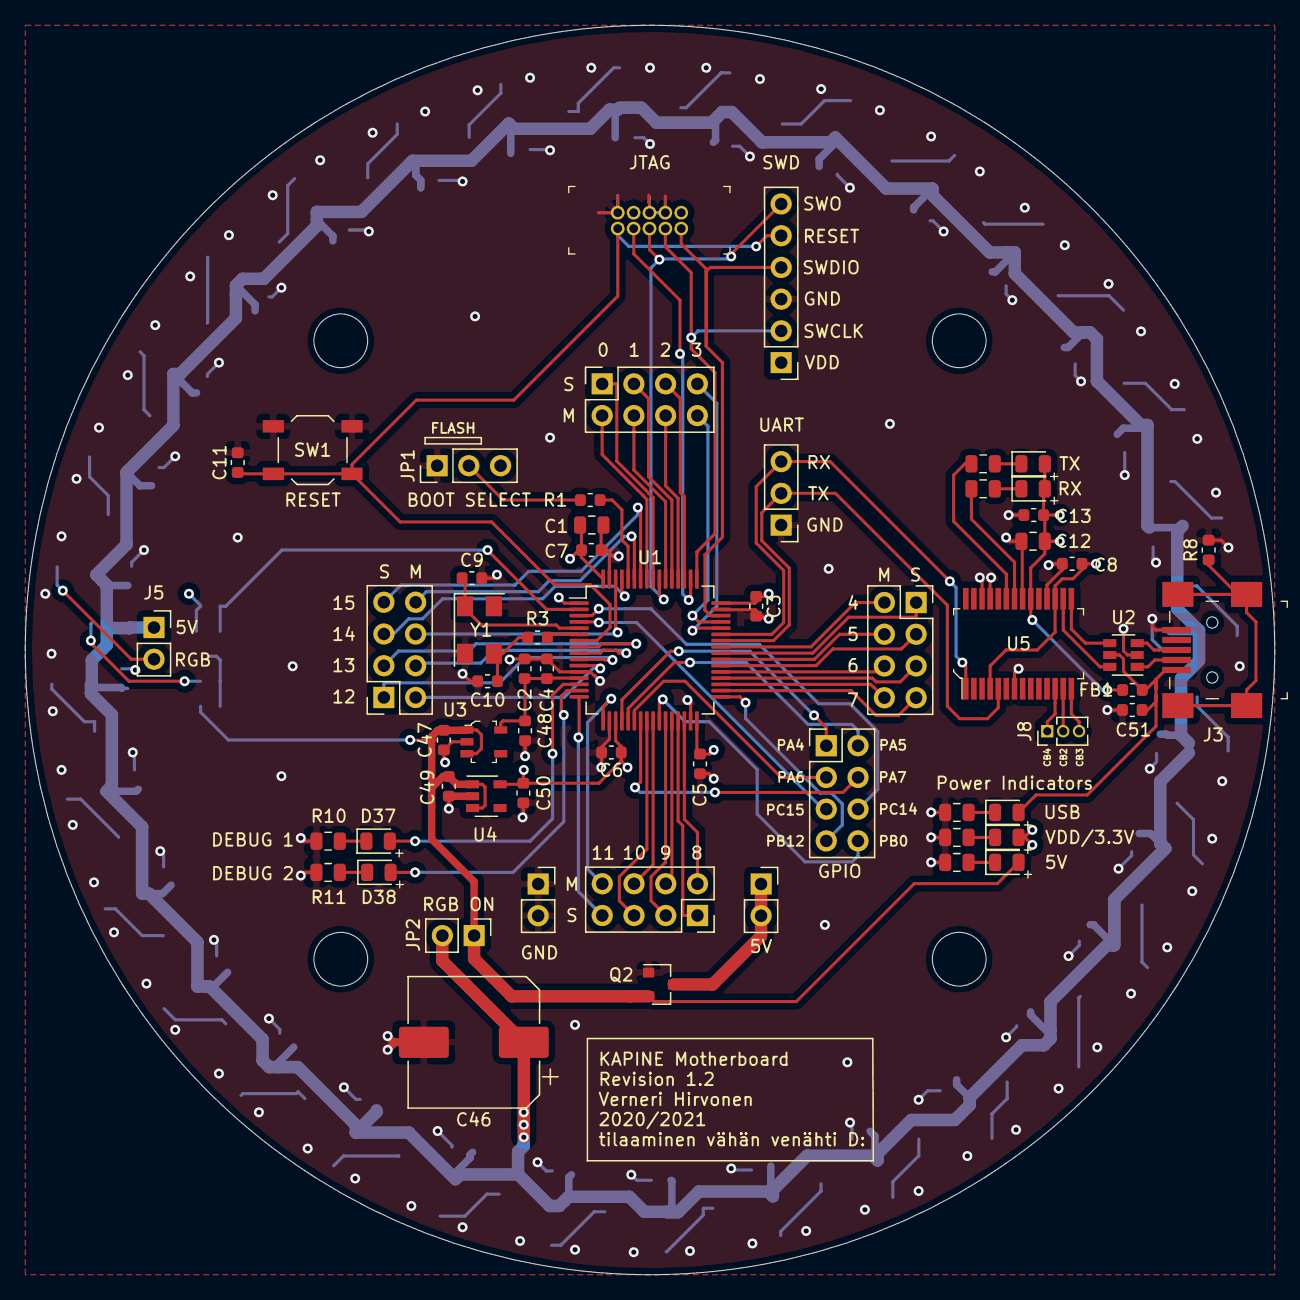
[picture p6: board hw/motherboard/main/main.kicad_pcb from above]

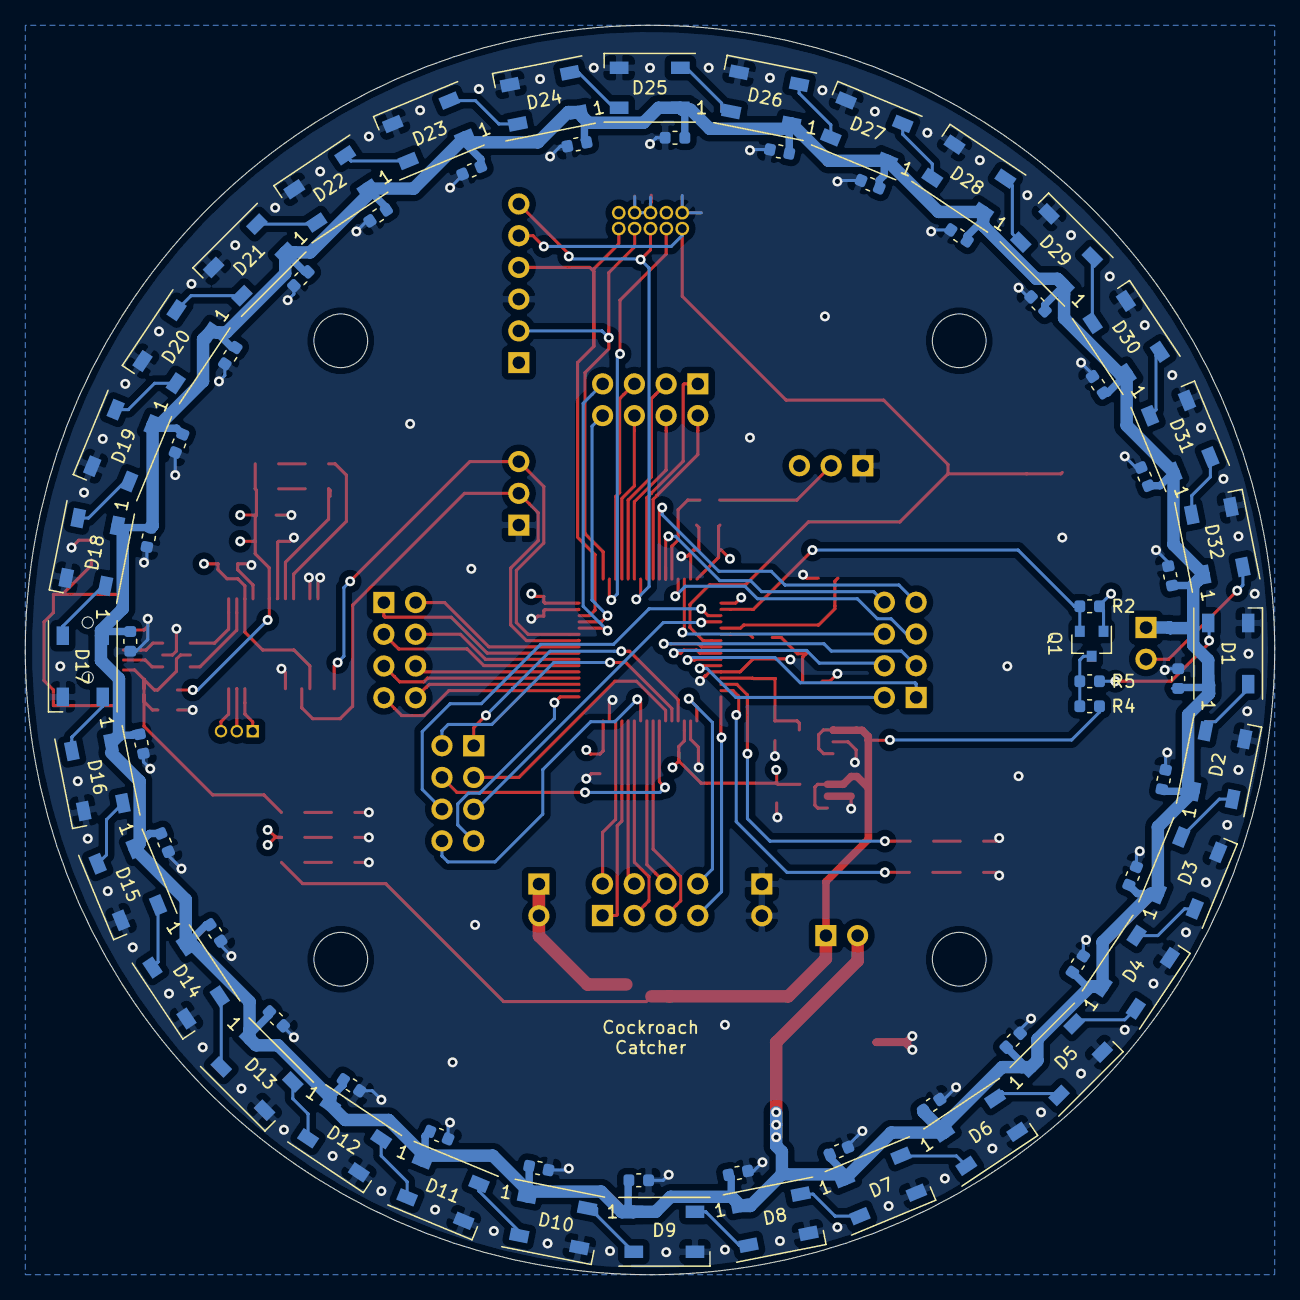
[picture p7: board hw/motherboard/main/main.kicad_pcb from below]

Board: 4 copper layers, 100.0 x 100.0 mm, 132 parts (68 on the bottom side), 115 nets.

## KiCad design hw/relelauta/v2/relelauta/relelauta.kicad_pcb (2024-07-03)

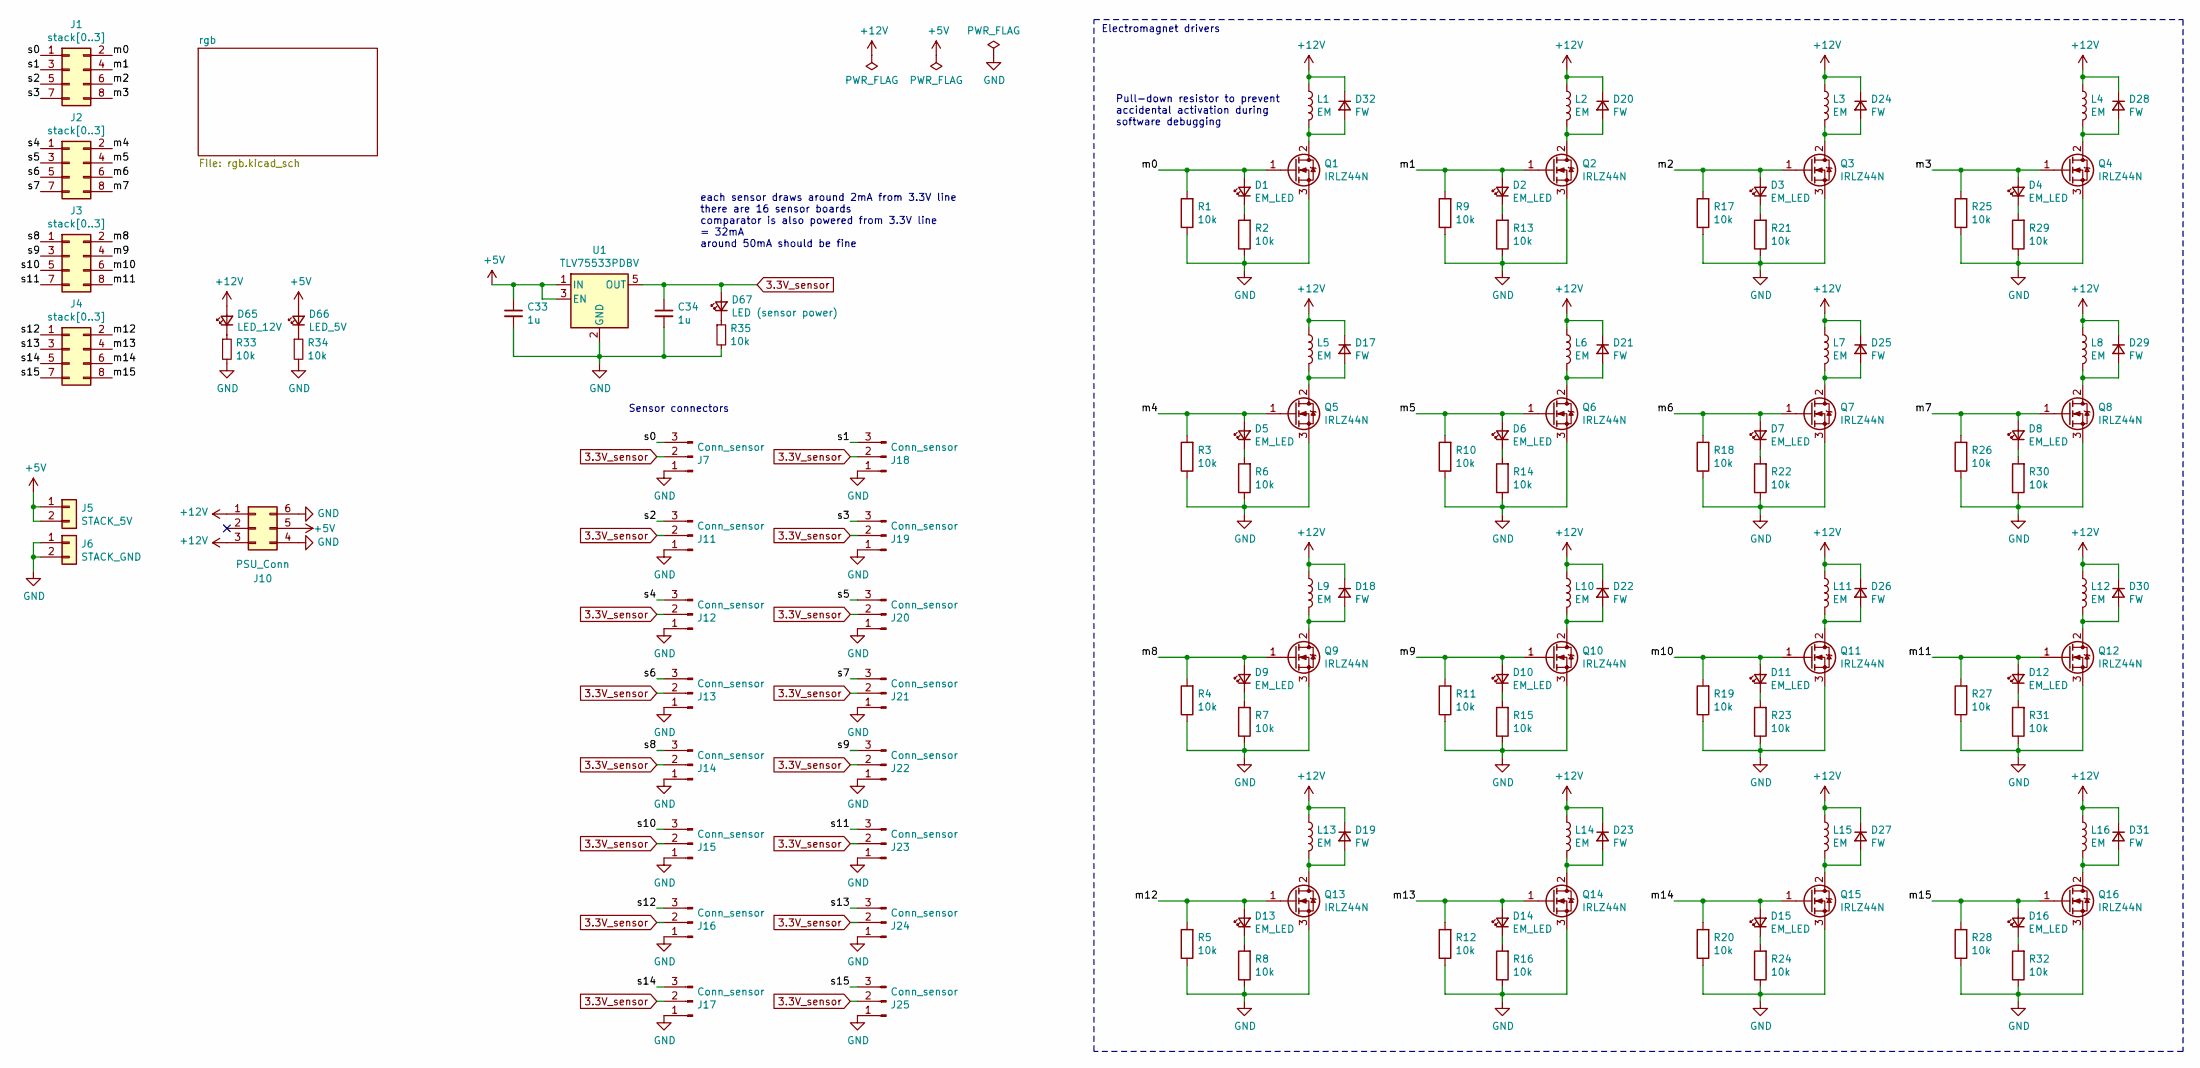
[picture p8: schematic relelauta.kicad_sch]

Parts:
C33, C34: 1u; C_0603_1608Metric
D1, D2, D3, D4, D5, D6, D7, D8, D9, D10, D11, D12, D13, D14, D15, D16: EM_LED; LED_0805_2012Metric
D17, D18, D19, D20, D21, D22, D23, D24, D25, D26, D27, D28, D29, D30, D31, D32: FW; D_DO-41_SOD81_P7.62mm_Horizontal
D65: LED_12V; LED_0805_2012Metric
D66: LED_5V; LED_0805_2012Metric
D67: LED (sensor power); LED_0805_2012Metric
J1, J2, J3, J4: stack[0..3]; PinSocket_2x04_P2.54mm_Vertical
J5: STACK_5V; PinSocket_1x02_P2.54mm_Vertical
J6: STACK_GND; PinSocket_1x02_P2.54mm_Vertical
J7, J11, J12, J13, J14, J15, J16, J17, J18, J19, J20, J21, J22, J23, J24, J25: Conn_sensor; PinHeader_1x03_P2.54mm_Horizontal
J10: PSU_Conn; Molex_Mini-Fit_Jr_5566-06A_2x03_P4.20mm_Vertical
L1, L2, L3, L4, L5, L6, L7, L8, L9, L10, L11, L12, L13, L14, L15, L16: EM; TerminalBlock_bornier-2_P5.08mm
Q1, Q2, Q3, Q4, Q5, Q6, Q7, Q8, Q9, Q10, Q11, Q12, Q13, Q14, Q15, Q16: IRLZ44N; TO-220-3_Vertical
R1, R2, R3, R4, R5, R6, R7, R8, R9, R10, R11, R12, R13, R14, R15, R16, R17, R18, R19, R20, R21, R22, R23, R24, R25, R26, R27, R28, R29, R30, R31, R32: 10k; R_0603_1608Metric
R33, R34, R35: 10k; R_0805_2012Metric
U1: TLV75533PDBV; SOT-23-5

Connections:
3.3V_sensor: C34.1, D67.2 (A), J7.2, J11.2, J12.2, J13.2, J14.2, J15.2, J16.2, J17.2, J18.2, J19.2, J20.2, J21.2, J22.2, J23.2, J24.2, J25.2, U1.5 (OUT)
+5V: C33.1, D66.2 (A), J5.1, J5.2, J10.5, U1.1 (IN), U1.3 (EN)
+12V: D17.1 (K), D18.1 (K), D19.1 (K), D20.1 (K), D21.1 (K), D22.1 (K), D23.1 (K), D24.1 (K), D25.1 (K), D26.1 (K), D27.1 (K), D28.1 (K), D29.1 (K), D30.1 (K), D31.1 (K), D32.1 (K), D65.2 (A), J10.1, J10.3, L1.1, L2.1, L3.1, L4.1, L5.1, L6.1, L7.1, L8.1, L9.1, L10.1, L11.1, L12.1, L13.1, L14.1, L15.1, L16.1
/m0: D1.2 (A), J1.2, Q1.1 (G), R1.2
/m1: D2.2 (A), J1.4, Q2.1 (G), R9.2
/m2: D3.2 (A), J1.6, Q3.1 (G), R17.2
/m3: D4.2 (A), J1.8, Q4.1 (G), R25.2
/m4: D5.2 (A), J2.2, Q5.1 (G), R3.2
/m5: D6.2 (A), J2.4, Q6.1 (G), R10.2
/m6: D7.2 (A), J2.6, Q7.1 (G), R18.2
/m7: D8.2 (A), J2.8, Q8.1 (G), R26.2
/m8: D9.2 (A), J3.2, Q9.1 (G), R4.2
/m9: D10.2 (A), J3.4, Q10.1 (G), R11.2
/m10: D11.2 (A), J3.6, Q11.1 (G), R19.2
/m11: D12.2 (A), J3.8, Q12.1 (G), R27.2
/m12: D13.2 (A), J4.2, Q13.1 (G), R5.2
/m13: D14.2 (A), J4.4, Q14.1 (G), R12.2
/m14: D15.2 (A), J4.6, Q15.1 (G), R20.2
/m15: D16.2 (A), J4.8, Q16.1 (G), R28.2
/s0: J1.1, J7.3
/s1: J1.3, J18.3
/s2: J1.5, J11.3
/s3: J1.7, J19.3
/s4: J2.1, J12.3
/s5: J2.3, J20.3
/s6: J2.5, J13.3
/s7: J2.7, J21.3
/s8: J3.1, J14.3
/s9: J3.3, J22.3
/s10: J3.5, J15.3
/s11: J3.7, J23.3
/s12: J4.1, J16.3
/s13: J4.3, J24.3
/s14: J4.5, J17.3
/s15: J4.7, J25.3
GND: C33.2, C34.2, J6.1, J6.2, J7.1, J10.4, J10.6, J11.1, J12.1, J13.1, J14.1, J15.1, J16.1, J17.1, J18.1, J19.1, J20.1, J21.1, J22.1, J23.1, J24.1, J25.1, Q1.3 (S), Q2.3 (S), Q3.3 (S), Q4.3 (S), Q5.3 (S), Q6.3 (S), Q7.3 (S), Q8.3 (S), Q9.3 (S), Q10.3 (S), Q11.3 (S), Q12.3 (S), Q13.3 (S), Q14.3 (S), Q15.3 (S), Q16.3 (S), R1.1, R2.1, R3.1, R4.1, R5.1, R6.1, R7.1, R8.1, R9.1, R10.1, R11.1, R12.1, R13.1, R14.1, R15.1, R16.1, R17.1, R18.1, R19.1, R20.1, R21.1, R22.1, R23.1, R24.1, R25.1, R26.1, R27.1, R28.1, R29.1, R30.1, R31.1, R32.1, R33.2, R34.2, R35.2, U1.2 (GND); also elsewhere on the board
unnamed: D1.1 (K), R2.2
unnamed: D2.1 (K), R13.2
unnamed: D3.1 (K), R21.2
unnamed: D4.1 (K), R29.2
unnamed: D5.1 (K), R6.2
unnamed: D6.1 (K), R14.2
unnamed: D7.1 (K), R22.2
unnamed: D8.1 (K), R30.2
unnamed: D9.1 (K), R7.2
unnamed: D10.1 (K), R15.2
unnamed: D11.1 (K), R23.2
unnamed: D12.1 (K), R31.2
unnamed: D13.1 (K), R8.2
unnamed: D14.1 (K), R16.2
unnamed: D15.1 (K), R24.2
unnamed: D16.1 (K), R32.2
unnamed: D17.2 (A), L5.2, Q5.2 (D)
unnamed: D18.2 (A), L9.2, Q9.2 (D)
unnamed: D19.2 (A), L13.2, Q13.2 (D)
unnamed: D20.2 (A), L2.2, Q2.2 (D)
unnamed: D21.2 (A), L6.2, Q6.2 (D)
unnamed: D22.2 (A), L10.2, Q10.2 (D)
unnamed: D23.2 (A), L14.2, Q14.2 (D)
unnamed: D24.2 (A), L3.2, Q3.2 (D)
unnamed: D25.2 (A), L7.2, Q7.2 (D)
unnamed: D26.2 (A), L11.2, Q11.2 (D)
unnamed: D27.2 (A), L15.2, Q15.2 (D)
unnamed: D28.2 (A), L4.2, Q4.2 (D)
unnamed: D29.2 (A), L8.2, Q8.2 (D)
unnamed: D30.2 (A), L12.2, Q12.2 (D)
unnamed: D31.2 (A), L16.2, Q16.2 (D)
unnamed: D32.2 (A), L1.2, Q1.2 (D)
unnamed: D65.1 (K), R33.1
unnamed: D66.1 (K), R34.1
unnamed: D67.1 (K), R35.1

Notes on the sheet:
Pull-down resistor to prevent accidental activation during software debugging
each sensor draws around 2mA from 3.3V line there are 16 sensor boards comparator is also powered from 3.3V line = 32mA around 50mA should be fine
Sensor connectors
Electromagnet drivers

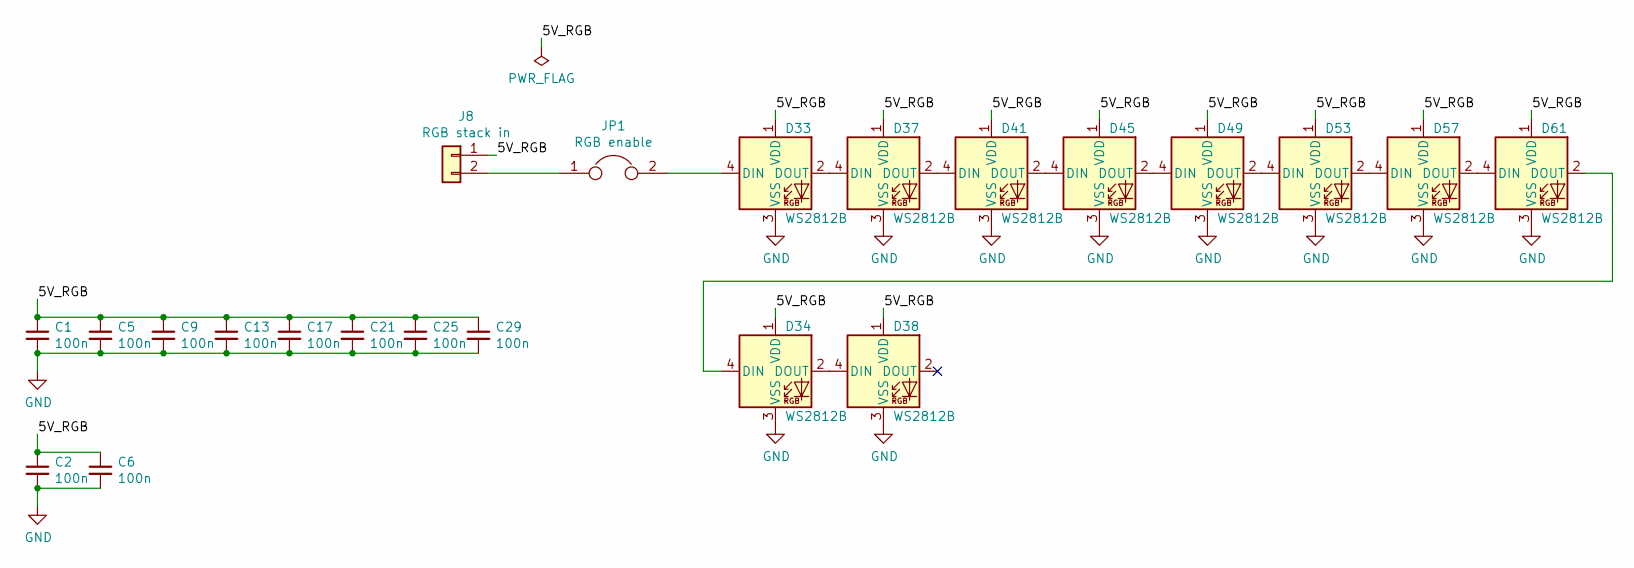
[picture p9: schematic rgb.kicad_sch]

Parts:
C1, C2, C5, C6, C9, C13, C17, C21, C25, C29: 100n; C_0603_1608Metric
D33, D34, D37, D38, D41, D45, D49, D53, D57, D61: WS2812B; LED_WS2812B_PLCC4_5.0x5.0mm_P3.2mm
J8: RGB stack in; PinSocket_1x02_P2.54mm_Vertical
JP1: RGB enable; PinHeader_2x01_P2.54mm_Vertical

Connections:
/rgb/5V_RGB: C1.1, C2.1, C5.1, C6.1, C9.1, C13.1, C17.1, C21.1, C25.1, C29.1, D33.1 (VDD), D34.1 (VDD), D37.1 (VDD), D38.1 (VDD), D41.1 (VDD), D45.1 (VDD), D49.1 (VDD), D53.1 (VDD), D57.1 (VDD), D61.1 (VDD), J8.1
GND: C1.2, C2.2, C5.2, C6.2, C9.2, C13.2, C17.2, C21.2, C25.2, C29.2, D33.3 (VSS), D34.3 (VSS), D37.3 (VSS), D38.3 (VSS), D41.3 (VSS), D45.3 (VSS), D49.3 (VSS), D53.3 (VSS), D57.3 (VSS), D61.3 (VSS); also elsewhere on the board
unnamed: D33.2 (DOUT), D37.4 (DIN)
unnamed: D33.4 (DIN), JP1.2
unnamed: D34.2 (DOUT), D38.4 (DIN)
unnamed: D34.4 (DIN), D61.2 (DOUT)
unnamed: D37.2 (DOUT), D41.4 (DIN)
unnamed: D41.2 (DOUT), D45.4 (DIN)
unnamed: D45.2 (DOUT), D49.4 (DIN)
unnamed: D49.2 (DOUT), D53.4 (DIN)
unnamed: D53.2 (DOUT), D57.4 (DIN)
unnamed: D57.2 (DOUT), D61.4 (DIN)
unnamed: J8.2, JP1.1

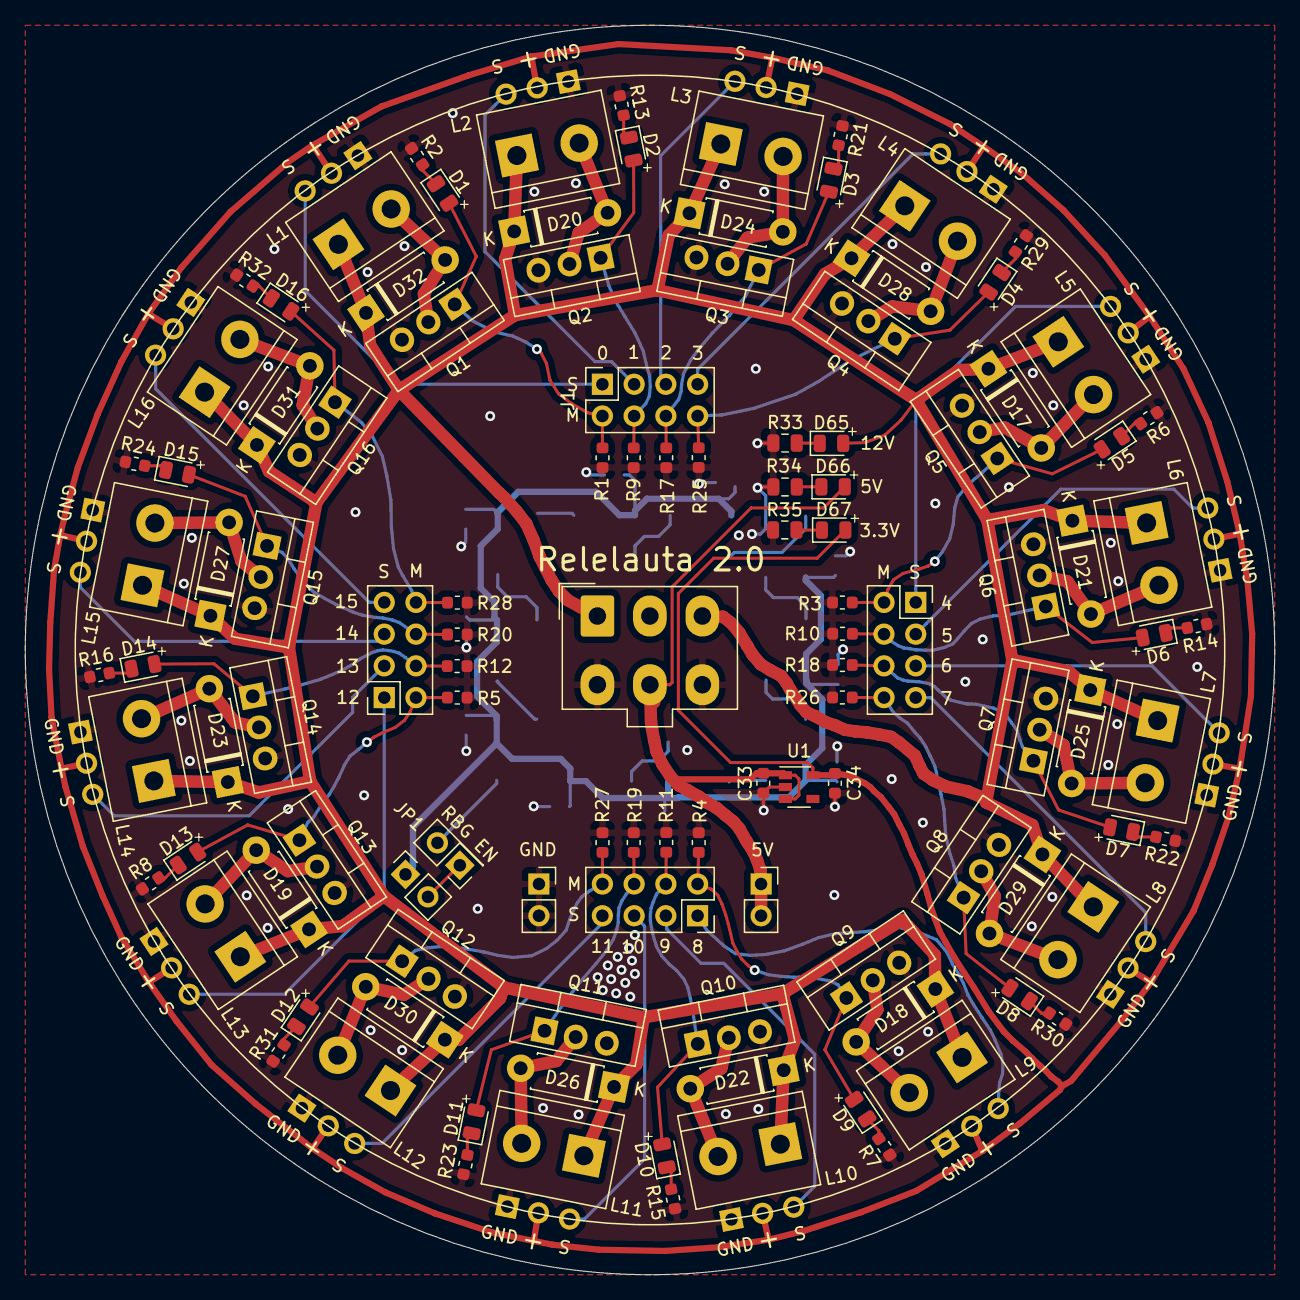
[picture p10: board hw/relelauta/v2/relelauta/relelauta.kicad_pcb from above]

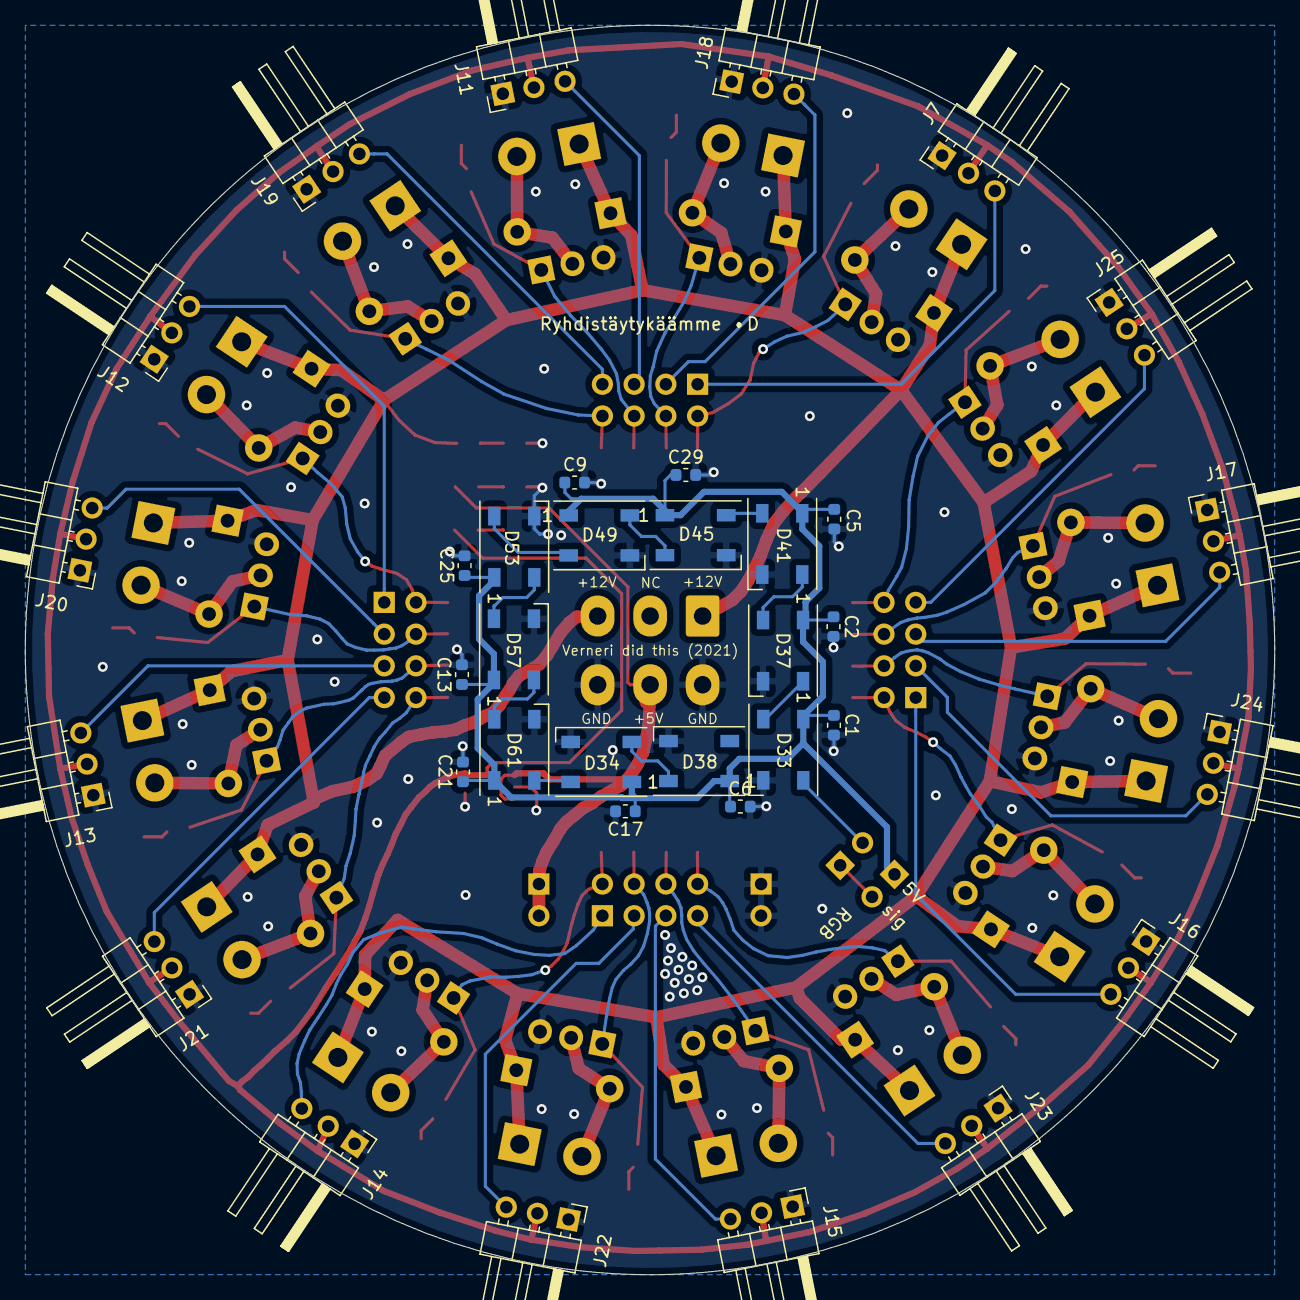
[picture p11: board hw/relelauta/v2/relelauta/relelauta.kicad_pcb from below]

Board: 2 copper layers, 100.0 x 100.0 mm, 150 parts (36 on the bottom side), 83 nets.

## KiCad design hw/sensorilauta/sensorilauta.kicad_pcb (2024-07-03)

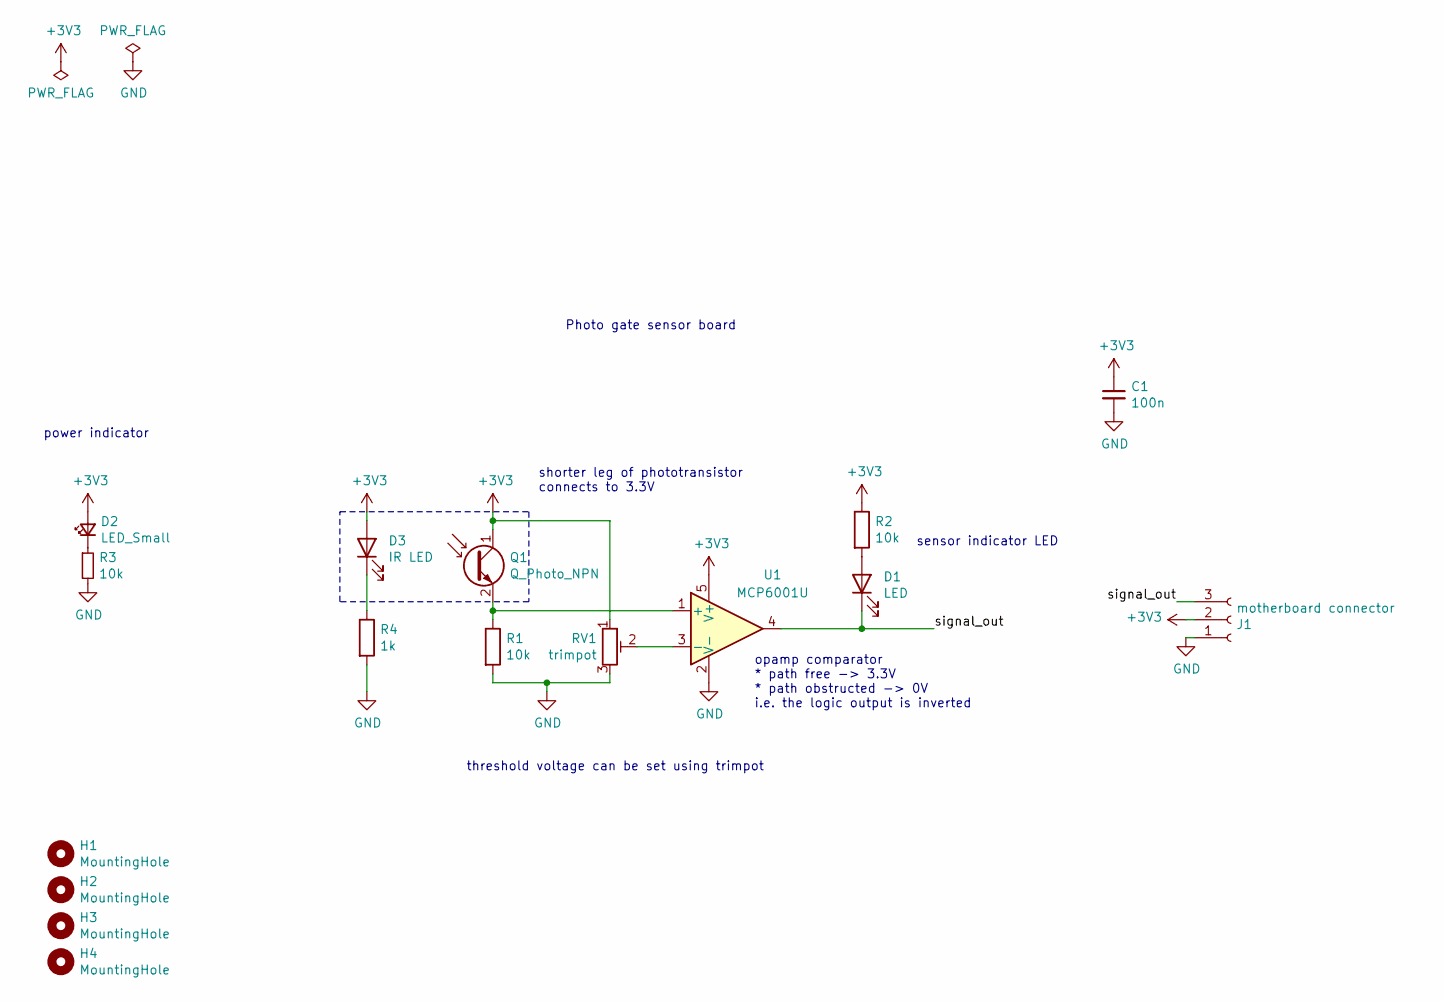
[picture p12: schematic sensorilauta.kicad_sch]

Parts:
C1: 100n; C_0805_2012Metric_Pad1.15x1.40mm_HandSolder
D1: LED; LED_D5.0mm
D2: LED_Small; LED_0805_2012Metric_Castellated
D3: IR LED; PinHeader_2x01_P2.54mm_Vertical
H1, H2, H3, H4: MountingHole; MountingHole_4.3mm_M4
J1: motherboard connector; PinHeader_1x03_P2.54mm_Horizontal
Q1: Q_Photo_NPN; PinHeader_2x01_P2.54mm_Vertical
R1, R2, R3: 10k; R_0805_2012Metric_Pad1.15x1.40mm_HandSolder
R4: 1k; R_0805_2012Metric_Pad1.15x1.40mm_HandSolder
RV1: trimpot; Potentiometer_Vishay_TS53YJ_Vertical
U1: MCP6001U; SOT-23-5_HandSoldering

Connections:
+3V3: C1.1, D2.2 (A), D3.2 (A), J1.2, Q1.1 (C), R2.1, RV1.1, U1.5 (V+)
/signal_out: D1.1 (K), J1.3, U1.4
GND: C1.2, J1.1, R1.2, R3.2, R4.2, RV1.3, U1.2 (V-)
unnamed: D1.2 (A), R2.2
unnamed: D2.1 (K), R3.1
unnamed: D3.1 (K), R4.1
unnamed: Q1.2 (E), R1.1, U1.1 (+)
unnamed: RV1.2, U1.3 (-)

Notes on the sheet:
power indicator
sensor indicator LED
threshold voltage can be set using trimpot
Photo gate sensor board
opamp comparator * path free -> 3.3V * path obstructed -> 0V i.e. the logic output is inverted
shorter leg of phototransistor connects to 3.3V


Board: 2 copper layers, 29.2 x 29.5 mm, 16 parts (0 on the bottom side), 8 nets.

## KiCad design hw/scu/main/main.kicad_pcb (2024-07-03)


Board: 2 copper layers, 27 parts (0 on the bottom side), 16 nets.

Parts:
C1, C2, C3, C5, C7: 100n; C_0603_1608Metric
C4, C9, C11: 4.7u; C_0603_1608Metric
C6: 10n; C_0603_1608Metric
C8, C10, C12: 1u; C_0603_1608Metric
C13: 10u; C_0603_1608Metric
D1, D2: LED; LED_0805_2012Metric
J1: Conn_01x03_MountingPin; Molex_PicoBlade_53261-0371_1x03-1MP_P1.25mm_Horizontal
J2: Conn_01x06_MountingPin; Molex_PicoBlade_53261-0671_1x06-1MP_P1.25mm_Horizontal
L1: 10u; L_0603_1608Metric
R1, R2, R3, R4: 10k; R_0603_1608Metric
R5: 470k; R_0603_1608Metric
SW1: SW_Push; SW_SPST_TL3342
U1: STM32F072C8Tx; LQFP-48_7x7mm_P0.5mm
U2: LM3670MF; TSOT-23-5
U3: LP5907MFX-3.3; SOT-23-5

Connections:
/3V3_A: C6.1, C8.1, C12.1, U1.9, U3.5
/3V3_D: C1.1, C2.1, C3.1, C4.1, C7.1, C9.1, C13.1, J2.1, L1.2, R4.2, U1.1, U1.24, U1.36, U1.48, U2.4
/LED_1: D1.2, U1.27
/LED_2: D2.2, U1.28
/NRST: C5.1, J2.5, SW1.2, U1.7
/SWCLK: J2.2, U1.37
/SWDIO: J2.4, U1.34
/USART1_RX: J1.3, U1.31
/USART1_TX: J1.2, U1.30
/V_USB: C10.1, C11.1, R5.1, U2.1, U2.3, U3.1
GND: C1.2, C2.2, C3.2, C4.2, C5.2, C6.2, C7.2, C8.2, C9.2, C10.2, C11.2, C12.2, C13.2, J1.1, J1.MP, J2.3, J2.MP, R1.2, R2.1, R3.1, SW1.1, U1.8, U1.23, U1.35, U1.47, U2.2, U3.2
unnamed: D1.1, R2.2
unnamed: D2.1, R3.2
unnamed: L1.1, U2.5
unnamed: R1.1, R4.1, U1.44
unnamed: R5.2, U3.3

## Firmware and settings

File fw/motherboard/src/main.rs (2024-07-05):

// #![deny(unsafe_code)]
#![no_main]
#![no_std]

use rtic::app;
use rtic_monotonics::systick::prelude::*;

use panic_probe as _;
use defmt_rtt as _;

use stm32f3xx_hal::{
    gpio::{Output, PXx, PushPull},
    prelude::*,
};

// UART receive FSM STATE
#[derive(Debug)]
pub enum RxState {
    Sync1,
    Sync2,
    Command,
    Length,
    Payload(u8),
    Crc1,
    Crc2,
}

use stm32f3xx_hal::gpio::gpioa;
pub struct GpioaRegs {
    moder: gpioa::MODER,
    otyper: gpioa::OTYPER,
    afrl: gpioa::AFRL,
}

systick_monotonic!(Mono, 1000);

#[app(
        device = stm32f3xx_hal::pac,
        peripherals = true,
        dispatchers = [USB_HP, USB_LP, USB_WKUP_EXTI, TIM20_BRK]
        // dispatchers = [USB_HP, USB_LP, USB_WKUP_EXTI, TIM20_BRK, TIM20_UP, TIM20_TRG_COM, TIM20_CC, SPI4, I2C3_ER, I2C3_EV]
)]
mod app {
    use stm32f3xx_hal::{gpio::{self, gpioa::{self, Parts}, marker::Gpio, Pin, AF5, PA5, PA6, PA7, U}, pac::{DMA1, GPIOA, SPI1}, rcc::{Enable, Reset}, spi::Spi};

    use super::*;
    const SENSOR_LUT: [usize; 16] = [13, 9, 11, 2, 0, 12, 15, 5, 14, 4, 8, 3, 1, 7, 10, 6];

    #[shared]
    struct Shared<Mode> {
        magnets: [PXx<Output<PushPull>>; 16],
        dma1: DMA1,
    }

    #[local]
    struct Local {
        debug_leds: [PXx<Output<PushPull>>; 2],
        local_cnt: u8,
        spi1: SPI1,
        // spi: Spi<SPI1, (PA5<AF5<PushPull>>, PA6<AF5<PushPull>>, PA7<AF5<PushPull>>)>
    }

    #[init]
    fn init(cx: init::Context) -> (Shared, Local) {
        // hprintln!("init").unwrap();

        let mut core = cx.core;
        let device = cx.device;

        let mut flash = device.FLASH.constrain();
        let mut rcc = device.RCC.constrain();

        let mut exti = device.EXTI;
        let mut syscfg = device.SYSCFG.constrain(&mut rcc.apb2);

        // configure clocks
        let clocks = rcc
            .cfgr
            .use_hse(8.MHz())
            .sysclk(72.MHz())
            .hclk(72.MHz())
            .pclk1(36.MHz())
            .pclk2(72.MHz())
            .freeze(&mut flash.acr);


        // Initialize (enable) the monotonic timer (CYCCNT)
        // core.DCB.enable_trace();
        // core.DWT.enable_cycle_counter();

        Mono::start(core.SYST, 72_000_000);

        // Acquire GPIO peripherals
        let mut gpio_a = device.GPIOA.split(&mut rcc.ahb);
        let mut gpio_b = device.GPIOB.split(&mut rcc.ahb);
        let mut gpio_c = device.GPIOC.split(&mut rcc.ahb);
        let mut gpio_d = device.GPIOD.split(&mut rcc.ahb);
        let mut _gpio_e = device.GPIOE.split(&mut rcc.ahb);
        let mut _gpio_f = device.GPIOF.split(&mut rcc.ahb);
        let mut _gpio_g = device.GPIOG.split(&mut rcc.ahb);
        let mut _gpio_h = device.GPIOH.split(&mut rcc.ahb);

        // let uart_pins = (
        //     gpio_a
        //         .pa9
        //         .into_af_push_pull(&mut gpio_a.moder, &mut gpio_a.otyper, &mut gpio_a.afrh),
        //     gpio_a
        //         .pa10
        //         .into_af_push_pull(&mut gpio_a.moder, &mut gpio_a.otyper, &mut gpio_a.afrh),
        // );

        // use SPI1 peripheral to drive WS2812B RGB leds
        let spi1_mosi = gpio_a
            .pa7
            .into_af_push_pull::<5>(&mut gpio_a.moder, &mut gpio_a.otyper, &mut gpio_a.afrl);

        // Manual SPI1 configuration
        let spi1 = device.SPI1;
        let dma1 = device.DMA1;

        SPI1::enable(&mut rcc.apb2); // enable SPI1 periperal
        SPI1::reset(&mut rcc.apb2); // reset SPI1 peripheral

        DMA1::enable(&mut rcc.ahb); // enable DMA controller peripheral
        dma1.ch3.cr.write(|w| {
            w.pl().very_high();
            w.msize().bits16();
            w.psize().bits16();
            w.minc().enabled(); // enable memory increment mode
            w.pinc().disabled(); // do not increment peripheral address
            w.dir().from_memory();
            w.tcie().enabled() // transfer complete interrupt enable
        });
        dma1.ch3.ndtr.write(|w| w.ndt().bits(24));  // 24 x u16

        spi1.cr2.write(|w| {
            w.ds().eight_bit(); // send 8-bit octets
            w.txdmaen().enabled(); // raise DMA request when TXE status bit is set (TXFIFO almost empty)
            w.ssoe().disabled()
        });
        
        spi1.cr1.write(|w| {
            w.mstr().master(); // enable master mode
            w.br().div16(); // set baud rate to 72M / 16 = 4.5 Ms
            w.lsbfirst().msbfirst(); // transmit MSB first
            w.ssm().enabled(); // software-defined slave select
            w.ssi().slave_not_selected(); // deassert chip-select
            w.bidimode().unidirectional();
            w.crcen().disabled();
            w.spe().enabled() // enable SPI peripheral
        });
        
        defmt::debug!("SPI1_CR1 = 0x{:08x}", spi1.cr1.read().bits());
        defmt::debug!("SPI1_CR2 = 0x{:08x}", spi1.cr2.read().bits());

        // spi1.dr.write(|w| w.dr().bits(0x1234));

        let spi_status = spi1.sr.read().bits();
        defmt::info!("spi status: 0x{:08x}", spi_status);

        // let mut spi1 = Spi::new(device.SPI1, (spi1_sck, spi1_miso, spi1_mosi), 5.MHz(), clocks, &mut rcc.apb2);


        // debug LEDs
        let mut debug_leds: [PXx<Output<PushPull>>; 2] = [
            gpio_a
                .pa0
                .into_push_pull_output(&mut gpio_a.moder, &mut gpio_a.otyper)
                .downgrade()
                .downgrade(),
            gpio_a
                .pa1
                .into_push_pull_output(&mut gpio_a.moder, &mut gpio_a.otyper)
                .downgrade()
                .downgrade(),
        ];

        // electromagnet outputs
        let mut magnets: [PXx<Output<PushPull>>; 16] = [
            gpio_b
                .pb5
                .into_push_pull_output(&mut gpio_b.moder, &mut gpio_b.otyper)
                .downgrade()
                .downgrade(),
            gpio_d
                .pd2
                .into_push_pull_output(&mut gpio_d.moder, &mut gpio_d.otyper)
                .downgrade()
                .downgrade(),
            gpio_c
                .pc11
                .into_push_pull_output(&mut gpio_c.moder, &mut gpio_c.otyper)
                .downgrade()
                .downgrade(),
            gpio_a
                .pa12
                .into_push_pull_output(&mut gpio_a.moder, &mut gpio_a.otyper)
                .downgrade()
                .downgrade(),
            gpio_a
                .pa8
                .into_push_pull_output(&mut gpio_a.moder, &mut gpio_a.otyper)
                .downgrade()
                .downgrade(),
            gpio_c
                .pc8
                .into_push_pull_output(&mut gpio_c.moder, &mut gpio_c.otyper)
                .downgrade()
                .downgrade(),
            gpio_c
                .pc6
                .into_push_pull_output(&mut gpio_c.moder, &mut gpio_c.otyper)
                .downgrade()
                .downgrade(),
            gpio_b
                .pb14
                .into_push_pull_output(&mut gpio_b.moder, &mut gpio_b.otyper)
                .downgrade()
                .downgrade(),
            gpio_b
                .pb11
                .into_push_pull_output(&mut gpio_b.moder, &mut gpio_b.otyper)
                .downgrade()
                .downgrade(),
            gpio_b
                .pb2
                .into_push_pull_output(&mut gpio_b.moder, &mut gpio_b.otyper)
                .downgrade()
                .downgrade(),
            gpio_c
                .pc5
                .into_push_pull_output(&mut gpio_c.moder, &mut gpio_c.otyper)
                .downgrade()
                .downgrade(),
            gpio_a
                .pa4
                .into_push_pull_output(&mut gpio_a.moder, &mut gpio_a.otyper)
                .downgrade()
                .downgrade(), // m11 (bodge)
            gpio_c
                .pc3
                .into_push_pull_output(&mut gpio_c.moder, &mut gpio_c.otyper)
                .downgrade()
                .downgrade(),
            gpio_c
                .pc1
                .into_push_pull_output(&mut gpio_c.moder, &mut gpio_c.otyper)
                .downgrade()
                .downgrade(),
            gpio_b
                .pb9
                .into_push_pull_output(&mut gpio_b.moder, &mut gpio_b.otyper)
                .downgrade()
                .downgrade(),
            gpio_b
                .pb7
                .into_push_pull_output(&mut gpio_b.moder, &mut gpio_b.otyper)
                .downgrade()
                .downgrade(),
        ];

        for magnet in &mut magnets {
            magnet
                .set_low()
                .expect("could not turn magnet off at startup");
        }


        defmt::info!("spawning software tasks");
        // spawn software tasks
        blink_task::spawn().unwrap();
        rgb_task::spawn().unwrap();

        defmt::info!("init done :)");

        (
            Shared {
                magnets,
                dma1,
            },
            Local {
                debug_leds,
                local_cnt: 0u8,
                spi1,
                // spi: spi1,
            },
        )
    }

    #[task(priority = 3, local = [debug_leds, local_cnt], shared=[magnets])]
    async fn blink_task(cx: blink_task::Context) {
        let mut magnets = cx.shared.magnets;
        loop {
            let idx = *cx.local.local_cnt;
            cx.local.debug_leds[0].toggle().expect("Could not toggle debug led");
            let mut magnets = magnets.lock(|mags| {
                mags[idx as usize].toggle().unwrap();
            });
            *cx.local.local_cnt = if *cx.local.local_cnt + 1 == 16 { 0 } else { *cx.local.local_cnt + 1 };
            Mono::delay(50.millis()).await;
        }
    }

    #[task(priority = 2, local = [spi1], shared = [dma1])]
    async fn rgb_task(mut cx: rgb_task::Context) {
        const ZERO: u8 = 0b1100_0000;
        const ONE: u8 = 0b1111_1100;

        let _sin_lut32: [u8; 32] = [128, 152, 176, 199, 218, 234, 246, 253, 255, 253, 246, 234, 218, 199, 176, 152, 128, 103, 79, 56, 37, 21, 9, 2, 0, 2, 9, 21, 37, 56, 79, 103];
        let sin_lut64: [u8; 64] = [128, 140, 152, 165, 176, 188, 198, 208, 218, 226, 234, 240, 245, 250, 253, 254, 255, 254, 253, 250, 245, 240, 234, 226, 218, 208, 198, 188, 176, 165, 152, 140, 128, 115, 103, 90, 79, 67, 57, 47, 37, 29, 21, 15, 10, 5, 2, 1, 0, 1, 2, 5, 10, 15, 21, 29, 37, 47, 57, 67, 79, 90, 103, 115];
        let _sin_lut128: [u8; 128] = [128, 134, 140, 146, 152, 158, 165, 170, 176, 182, 188, 193, 198, 203, 208, 213, 218, 222, 226, 230, 234, 237, 240, 243, 245, 248, 250, 251, 253, 254, 254, 255, 255, 255, 254, 254, 253, 251, 250, 248, 245, 243, 240, 237, 234, 230, 226, 222, 218, 213, 208, 203, 198, 193, 188, 182, 176, 170, 165, 158, 152, 146, 140, 134, 128, 121, 115, 109, 103, 97, 90, 85, 79, 73, 67, 62, 57, 52, 47, 42, 37, 33, 29, 25, 21, 18, 15, 12, 10, 7, 5, 4, 2, 1, 1, 0, 0, 0, 1, 1, 2, 4, 5, 7, 10, 12, 15, 18, 21, 25, 29, 33, 37, 42, 47, 52, 57, 62, 67, 73, 79, 85, 90, 97, 103, 109, 115, 121];
        
        const NUM_LEDS: usize = 32;
        const NUM_COLORS: usize = 3;
        const BYTES_PER_COLOR: usize = 8;
        const FRAME_BUF_SIZE: usize = (NUM_LEDS+1)*NUM_COLORS*BYTES_PER_COLOR;
        let mut frame_buf: [u8; FRAME_BUF_SIZE] = [ZERO; FRAME_BUF_SIZE];

        const LED_STRIDE: usize = NUM_COLORS*BYTES_PER_COLOR;
        
        let mut cnt: usize = 0;
        
        loop {
            
            // clear
            // first led is hardcoded to zeros to signal reset pulse
            for i in 0..FRAME_BUF_SIZE {
                if i < 24 {
                    frame_buf[i] = 0;
                } else {
                    frame_buf[i] = ZERO;
                }
            }
            
            // MSB first, order GRB
            for led in 0..NUM_LEDS {
                let g = sin_lut64[(cnt + led) & 0b111111];
                let r = sin_lut64[(cnt + led + 8) & 0b111111];
                let b = sin_lut64[(cnt + led + 24) & 0b111111];
                if (g >> 0) & 1 == 1 { frame_buf[(led+1)*LED_STRIDE + 7-0 + 0] = ONE };
                if (g >> 1) & 1 == 1 { frame_buf[(led+1)*LED_STRIDE + 7-1 + 0] = ONE };
                if (g >> 2) & 1 == 1 { frame_buf[(led+1)*LED_STRIDE + 7-2 + 0] = ONE };
                if (g >> 3) & 1 == 1 { frame_buf[(led+1)*LED_STRIDE + 7-3 + 0] = ONE };
                if (g >> 4) & 1 == 1 { frame_buf[(led+1)*LED_STRIDE + 7-4 + 0] = ONE };
                if (g >> 5) & 1 == 1 { frame_buf[(led+1)*LED_STRIDE + 7-5 + 0] = ONE };
                if (g >> 6) & 1 == 1 { frame_buf[(led+1)*LED_STRIDE + 7-6 + 0] = ONE };
                if (g >> 7) & 1 == 1 { frame_buf[(led+1)*LED_STRIDE + 7-7 + 0] = ONE };
                if (r >> 0) & 1 == 1 { frame_buf[(led+1)*LED_STRIDE + 7-0 + 8] = ONE };
                if (r >> 1) & 1 == 1 { frame_buf[(led+1)*LED_STRIDE + 7-1 + 8] = ONE };
                if (r >> 2) & 1 == 1 { frame_buf[(led+1)*LED_STRIDE + 7-2 + 8] = ONE };
                if (r >> 3) & 1 == 1 { frame_buf[(led+1)*LED_STRIDE + 7-3 + 8] = ONE };
                if (r >> 4) & 1 == 1 { frame_buf[(led+1)*LED_STRIDE + 7-4 + 8] = ONE };
                if (r >> 5) & 1 == 1 { frame_buf[(led+1)*LED_STRIDE + 7-5 + 8] = ONE };
                if (r >> 6) & 1 == 1 { frame_buf[(led+1)*LED_STRIDE + 7-6 + 8] = ONE };
                if (b >> 7) & 1 == 1 { frame_buf[(led+1)*LED_STRIDE + 7-7 + 8] = ONE };
                if (b >> 0) & 1 == 1 { frame_buf[(led+1)*LED_STRIDE + 7-0 + 16] = ONE };
                if (b >> 1) & 1 == 1 { frame_buf[(led+1)*LED_STRIDE + 7-1 + 16] = ONE };
                if (b >> 2) & 1 == 1 { frame_buf[(led+1)*LED_STRIDE + 7-2 + 16] = ONE };
                if (b >> 3) & 1 == 1 { frame_buf[(led+1)*LED_STRIDE + 7-3 + 16] = ONE };
                if (b >> 4) & 1 == 1 { frame_buf[(led+1)*LED_STRIDE + 7-4 + 16] = ONE };
                if (b >> 5) & 1 == 1 { frame_buf[(led+1)*LED_STRIDE + 7-5 + 16] = ONE };
                if (b >> 6) & 1 == 1 { frame_buf[(led+1)*LED_STRIDE + 7-6 + 16] = ONE };
                if (b >> 7) & 1 == 1 { frame_buf[(led+1)*LED_STRIDE + 7-7 + 16] = ONE };
            }

            // SPI transfer
            if cx.local.spi1.sr.read().txe().bit_is_set() {

                // DMA transfer for whole frame buf
                let spi1_dr_addr = core::ptr::addr_of!(cx.local.spi1.dr);
                cx.shared.dma1.lock(|dma1| {
                    dma1.ifcr.write(|w| w.ctcif3().set_bit());
                    let mem_ptr = core::ptr::addr_of!(frame_buf);
                    // defmt::debug!("mem_ptr = 0x{:08x}", mem_ptr);             
                    // TODO: Can this be done without unsafe?
                    // Set DMA transfer addresses
                    unsafe {
                        dma1.ch3.mar.write(|w| w.ma().bits(mem_ptr as u32));
                        dma1.ch3.par.write(|w| w.bits(spi1_dr_addr as u32));
                    }
                    dma1.ch3.ndtr.write(|w| w.ndt().bits((FRAME_BUF_SIZE/2) as u16));
    
                    // start DMA transfer
                    dma1.ch3.cr.modify(|_, w| w.en().enabled());
                });
            }
            // let status = cx.local.spi1.sr.read().bits();
            // defmt::trace!("spi status: 0x{:08x}", status);

            cnt = cnt.overflowing_add(1).0;
            Mono::delay(10.millis()).await;
        }
    }

    #[task(binds = DMA1_CH3, shared = [dma1])]
    fn handle_completed_dma_transfer(mut cx: handle_completed_dma_transfer::Context) {

        // disable DMA after completed transfer
        cx.shared.dma1.lock(|dma1| {
            if dma1.isr.read().tcif3().bit_is_set() {
                dma1.ch3.cr.modify(|_, w| w.en().disabled());
                dma1.ifcr.write(|w| w.ctcif3().set_bit());
            }
        });
    }
}

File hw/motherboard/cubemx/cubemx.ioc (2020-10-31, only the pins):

Mcu.UserName=STM32F303RETx
PC10.Signal=GPIO_Input
PC12.Signal=GPIO_Input
PB11.Signal=GPIO_Output
PB13.Signal=GPIO_Input
PB15.Signal=GPIO_Input
PA12.Signal=GPIO_Output
PB6.Signal=GPIO_Input
PC7.Signal=GPIO_Input
PC3.Signal=GPIO_Output
PB2.Signal=GPIO_Output
PB7.Signal=GPIO_Output
PA8.Signal=GPIO_Output
PA0.Signal=GPIO_Output
PB9.Signal=GPIO_Output
PB1.Signal=GPIO_Input
PA10.Signal=USART1_RX
PA15.Signal=SYS_JTDI
PC5.Signal=GPIO_Output
PB4.Signal=GPIO_Input
PA3.Signal=GPIO_Output
PC11.Signal=GPIO_Output
PC13.Signal=GPIO_Output
PC8.Signal=GPIO_Output
PC4.Signal=GPIO_Input
PC2.Signal=GPIO_Input
PC6.Signal=GPIO_Output
PC0.Signal=GPIO_Input
PA13.Signal=SYS_JTMS-SWDIO
PA9.Signal=USART1_TX
PA1.Signal=GPIO_Output
PB10.Signal=GPIO_Input
PB14.Signal=GPIO_Output
PA2.Signal=GPIO_Input
PB3.Signal=SYS_JTDO-TRACESWO
PB5.Signal=GPIO_Output
PA11.Signal=GPIO_Input
PA14.Signal=SYS_JTCK-SWCLK
PB8.Signal=GPIO_Input
PC9.Signal=GPIO_Input
PD2.Signal=GPIO_Output
PC1.Signal=GPIO_Output

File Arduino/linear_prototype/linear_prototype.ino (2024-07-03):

#define N_SENSORS 2
#define N_MAGNETS 4

// sensors
const int photogate_sensor_pins[] = {A0, A1};
const int photogate_led_pins[] = {2, 3};
int readings[N_SENSORS] = {0};
const int photogate_threshold = 200;

const int electromagnet_pins[] = {5, 6, 7, 8};

void setup() {
  // put your setup code here, to run once:
  for (int i = 0; i < N_SENSORS; i++)
  {
    pinMode(photogate_sensor_pins[i], INPUT);
    pinMode(photogate_led_pins[i], OUTPUT);
  }

  for (int i = 0; i < N_MAGNETS; i++)
  {
      pinMode(electromagnet_pins[i], OUTPUT);
      digitalWrite(electromagnet_pins[i], LOW);
  }
  Serial.begin(115200);
}

// accelerate until sensor_pin is pulled down or duration has elapsed
void ACCELERATE(int pin, int duration, int sensor_pin)
{
  int start = millis();
  digitalWrite(pin, HIGH); // ACCELERATE !!!
  while (millis() - start < duration)
  {
    // start listening to photogate
    int reading = analogRead(sensor_pin);
    if (reading < photogate_threshold)
    {
      break;
    }
  }
  digitalWrite(pin, LOW); // ACCELERATE !!!
}

// accelerate until sensor_pin is pulled down or duration has elapsed
void ACCELERATE2()
{
  digitalWrite(electromagnet_pins[3], HIGH);
  delay(30);
  digitalWrite(electromagnet_pins[3], LOW);

  // magnet 2
  const int timeout = 300;
  int start = millis();
  // digitalWrite(electromagnet_pins[3], HIGH); // ACCELERATE !!!
  digitalWrite(electromagnet_pins[2], HIGH); // ACCELERATE !!!

  while (millis() - start < timeout)
  {
    // start listening to photogate
    int reading = analogRead(photogate_sensor_pins[1]);
    if (reading < photogate_threshold)
    {
      break;
    }
  }
  Serial.println(String()+"time elapsed"+(millis() - start));
  // digitalWrite(electromagnet_pins[3], LOW);
  digitalWrite(electromagnet_pins[2], LOW);

  digitalWrite(electromagnet_pins[1], HIGH);
  delay(50);
  digitalWrite(electromagnet_pins[1], LOW);

  // magnets 0 and 1
  start = millis();
  // digitalWrite(electromagnet_pins[1], HIGH); // ACCELERATE !!!
  digitalWrite(electromagnet_pins[0], HIGH); // ACCELERATE !!!

  while (millis() - start < timeout)
  {
    // start listening to photogate
    int reading = analogRead(photogate_sensor_pins[0]);
    if (reading < photogate_threshold)
    {
      break;
    }
  }
  // digitalWrite(electromagnet_pins[1], LOW);
  digitalWrite(electromagnet_pins[0], LOW);
}

int accel_duration = 1000;
void loop() {
  ACCELERATE2();
  exit(0);

  /*
  // ACCELERATE(electromagnet_pin, 40);
  // send data only when you receive data:
  if (Serial.available() > 0)
  {
    // read the incoming byte:
    String command = Serial.readString();

    if (command == "a")
    {
      Serial.print("ACCELERATE!!! ");
      //ACCELERATE(electromagnet_pins[0], accel_duration, A1);
      ACCELERATE2();
      Serial.println("done");
    }
    else if (command == "+")
    {
      Serial.println(String()+"Duration: "+accel_duration);
      accel_duration += 5;
    }
    else if (command == "-")
    {
      Serial.println(String()+"Duration: "+accel_duration);
      accel_duration -= 5;
    }
    else
    {
      Serial.println(String()+"Unknown command: "+command);
    }
  }
  */

  // start listening to photogate (photogate debug leds)
  /*
  for (int i = 0; i < N_SENSORS; i++)
  {
    readings[i] = analogRead(photogate_sensor_pins[i]);
    digitalWrite(photogate_led_pins[i], (readings[i] < photogate_threshold) ? HIGH : LOW); // set photogate led if reading is below the threshold
  }
  */

  // loop at 100 Hz for now
  delay(10);
}

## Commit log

2019-05-28 Completed board schematic
    [relelauta.kicad_pcb, relelauta.sch]
2019-05-28 Add test points and useful connectors
    [relelauta.sch]
2019-05-29 Completed PCB layout
    [relelauta-B_Cu.gbr, relelauta-B_Mask.gbr, relelauta-B_SilkS.gbr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]
2019-05-29 Fixed NPN transistors on the wrong side of load in the schematic by changing them to PNP transistors.
    [relelauta.sch]
2019-07-06 Working prototype 1 acceleration sequence
2020-02-07 Add reference design for STM32F373
    [main.kicad_pcb, main.sch]
2020-02-07 Add RGB leds to schematic
    [main.sch, rgb.sch]
2020-08-17 WIP save progress before including digikey kicad library
2020-08-17 Add digikey-kicad-library schematic symbols to motherboard project
2020-08-17 Add digikey-kicad-library footprints to motherboard project
2020-08-24 Add cubemx project for pin configuration.
    [main.sch]
2020-08-24 WIP Start motherboard PCB layout.
    [main.kicad_pcb, main.sch, rgb.sch]
2020-09-01 WIP Add electromagnet and sensor schematic connections to MCU pins
    [main.kicad_pcb, main.sch, power.sch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]
2020-09-01 Lay out motherboard hardware revision 1
    [main.kicad_pcb, main.sch]
2020-09-02 Minor motherboard layout changes. Bump revision number to 1.1.
    [main.kicad_pcb, main.sch, power.sch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]
2020-09-03 Add missing component values.
    [main.kicad_pcb, main.sch, power.sch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]
2020-09-03 Add reverse polarity protection to +5V input. Bump revision number to 1.2.
    [main.kicad_pcb, main.sch, power.sch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]
2021-06-02 Add RGB LED microcontroller pin to pinout
2024-07-03 Check in incomplete SCU hardware
    [main.kicad_pcb, main.kicad_sch, main.sch]
2024-07-03 Add back digikey-kicad-library
2024-07-03 Create directory for arduino code
2024-07-03 Check in Arduino sketch from old linear prototype
2024-07-03 Reorganize project directory
    [relelauta-B_Cu.gbr, relelauta-B_Mask.gbr, relelauta-B_SilkS.gbr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]
2024-07-03 Add electromagnet driver schematics
    [relelauta.sch]
2024-07-03 Finish laying out relelauta v2.0 PCB. Minor tweaks to motherboard.
    [main-B_Cu.gbr, main-B_Mask.gbr, main-B_SilkS.gbr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]
2024-07-03 Add missing silkscreen markings
    [relelauta.kicad_pcb]
2024-07-03 Board layouts before checking gerbers for alignment
    [main.kicad_pcb, main.sch, power.sch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]
2024-07-03 Update KiCad files to KiCad 8
    [main.kicad_pcb, main.kicad_sch, power.kicad_sch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]
2024-07-03 Ignore gerbers
2024-07-03 Remove gerbers
    [main-B_Cu.gbr, main-B_Mask.gbr, main-B_SilkS.gbr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]
2024-07-03 Update sensorilauta files to KiCad 8
    [sensorilauta.kicad_pcb, sensorilauta.kicad_sch]
2024-07-03 Add stm32f1xx-hal blinky firmware
2024-07-03 New magnet driver demo firmware
2024-07-03 Configure firmware for STM32F303RE MCU
2024-07-03 WIP UART receiver with RTIC and interrupts
2024-07-03 WIP save progress before updating stm32f3xx-hal dependency
2024-07-03 WIP start fleshing out sensor interrupts, some hardware bodges are required
    [main.rs]
2024-07-03 Finish implementing interrupt handlers for sensor inputs
2024-07-03 Add safety timer for magnets
2024-07-03 WIP: update dependencies and start fixing resulting issues
    [main.rs]
2024-07-03 Something's still off with uart rx interrupts
2024-07-03 Somewhat working magnet on commands from PC
2024-07-04 Working SPI1 transfers, but successive octets are sent too slowly
    [main.rs]
2024-07-05 Workign sine LUT with one WS2812B led using custom SPI driver
2024-07-05 Laggy pulse animation using DMA transfers for LED values
2024-07-05 Kuul RGB animaatio, mutta yksi ledi lagittaa vielä 😢
